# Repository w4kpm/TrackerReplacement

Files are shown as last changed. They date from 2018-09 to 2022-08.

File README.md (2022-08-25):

# Tracker replacement #

Directory Descriptions:
   * ChibiOS - A linked repo for the embedded OS
   * Firmware - Firmware code for the back panel
   * FrontPanelFirmware - Firmware code for the front panel
   * KiCad - all board design files using OSS KiCad
   * Testing - python files used for original testing of the board
   * TrackerControlCode - code use in production for updating tracker position and for resetting errors remotely. 

Included in this repo:
   * Board design files for user interface panel and tracker controller
   * Firmware for both interface panel and tracker controller
   * Examples of software used to control, reset and poll the tracker.
   * In KiCad/TrackerBackPanel and KiCad/TrackerFrontPanel are directories for gerber for board production
   * in KiCad/TrackerBackPanel/BackPanel.csv and KiCad/TrackerFrontPanel/FrontPanel.csv are parts lists
   * pos files are also there for SMT parts
   * back panel used polou VNH5019 motor driver board Item #1451 to control the motor

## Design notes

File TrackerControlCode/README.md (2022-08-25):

# Tracker control software #

A few notes about the python files included here.

A redis server was used to coordinate the line for tracker updates and
for getting data off the line for reporting. Each time we try to
communicate with the tracker, we hold a lock on the line using
redislock.

## updateTrackerPos.py ##

This python file is called every 5 minutes from a cron job, each 5
minutes it uses the lat,long azimuth of the array and the current time
to determine the optimal angle of the array based on the sun
position. At the end of the day it starts backtracking.

Before each call, it reads sensors centrally located for the entire
array for both snow and wind.

If we detect snow, we physically write out a file to the computer - if
we have a power out situation, the file is persistent and will not
return to normal operations until it is manually cleared (i.e. we are
sure that all snow is off the panels)

If wind, it tabletops the array

Each tracker controller has a (typically) 5 degree hysterisis - so
there must be a more than 5 degree change in setpoint before the
tracker will try to move again.

Each tracker has 2 angle sensors on the front and back and typically
will average the angle between these two sensors. This was to ensure
that there was no slippage or difference between the front panel angle
and the back panel angle (we had problems at one point with this
happening)

Each tracker has a max amp rating and a 'soft' amp rating, if at any
time the amps from the motor go above the high amp rating it will flag
an error and if it goes above the soft rating for a time period it
will flag an error - resetTracker.py has been used to reset these
problems.

Possible error conditions are as follows:

* #define STRAIN_ERROR 1  = Amerage above 'soft' level for a preset time period
* #define FAST_BLOW_ERROR 2 = Amperage above 'high' amp level
* #define EAST_LIMIT_ERROR 3  = east limit switch activated
* #define WEST_LIMIT_ERROR 4 = west limit switch activated
* #define STALL_ERROR 5 = too long a time of no panel movement when the motor has been engaged
* #define ANGLE_DIFF_ERROR 6 = too much difference between front and back panel
* #define EAST_ANGLE_EXCEED_ERROR 7 = Angle too high in the east direction (software defined failsafe for limit switch) 
* #define WEST_ANGLE_EXCEED_ERROR 8 = Angle too high in the west direction (software defined failsafe for limit switch) 
* #define EMERGENCY_STOP_ERROR 9 = e stop activated at console

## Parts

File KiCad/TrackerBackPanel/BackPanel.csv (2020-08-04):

Id | Designator |  | Package | Quantity | Designation | MFG | MFG Ref | Supplier | Supplier_ref | SMD | Through | Total SMD | Total Through
1 | U5 |  | Pololu VNH5019 Breakout | 0 | VNH5019 | Not Populated |  |  |  |  |  |  | 0
2 | J1 |  | RJ45 | 1 | Conn_01x08 | Amphenol | RJHSE-5080 | Mouser | 523-RJHSE-5080 |  | 1 |  | 1
3 | C11,C9,C10,C4,C2,C6 | OK | C_1206_3216Metric | 6 | .1uF | Taiyo | HMK316B7104MLHT |  | Generic .1uF 1206 10% | 1 |  | 6 | 0
4 | F1,F4,F3,F2 | ij | R_1812_4532Metric | 4 | Polyfuse_Small | littlefuse | 1812L010DR | Mouser | 576-1812L010DR | 1 |  | 4 | 0
5 | H2,H3,H1,M4 |  | MountingHole_5.3mm_M5 | 0 | MountingHole_5.3mm_M5 | Not Populated |  |  |  |  |  | 0 | 0
6 | RV3,RV2,RV4,RV1 | IJ | R_1210_3225Metric | 4 | Varistor | AVX | VC121030S620DP | Mouser | 581-VC121030S620DP | 1 |  | 4 | 0
7 | D1,D2 | OK | SOT-23 | 2 | D_TVS_x2_AAC | Bourns | CDSOT23-SM712 | Mouser | 652-CDSOT23-SM712 | 1 |  | 2 | 0
8 | J9,J8 |  | TerminalBlock_Altech_AK300-4_P5.00mm | 2 | Conn_01x04 | Phoenix Contact | 1890989 | Mouser | 651-1890989 |  | 1 | 0 | 2
9 | J7,J6,J5,J4,J11 |  | TerminalBlock_Altech_AK300-2_P5.00mm | 5 | Conn_01x02 | Phoenix Contact | 1711026 | Mouser | 651-1711026 |  | 1 | 0 | 5
10 | C7,C3,C1,C5,C14,C15 | OK | C_1206_3216Metric | 6 | 1uF | vishay | VJ1206Y105KXQTW1BC |  | Generic 1uF 1206 10% | 1 |  | 6 | 0
11 | U4,U3 | OK | SOIC-8_3.9x4.9mm_P1.27mm | 2 | SN65HV7X | Texas Insturments | SN65HVD72D | mouser | 595-SN65HVD72D | 1 |  | 2 | 0
12 | U2 |  | TO-220-3_Vertical | 1 | R-78B3.3-2.0 | RECOM power | R-78E3.3-0.5 | Mouser | 919-R-78E3.3-0.5 |  | 1 | 0 | 1
13 | J2 |  | PinHeader_2x04_P2.54mm_Vertical | 0 | Conn_02x04_Odd_Even | Not Populated!! |  |  |  |  |  | 0 | 0
14 | J3 |  | PinHeader_1x06_P2.54mm_Vertical | 0 | Conn_01x06 | Not Populated!! |  |  |  |  |  | 0 | 0
15 | U1 | OK | LQFP-100_14x14mm_P0.5mm | 1 | STM32F303V(B-C)Tx_u | STM | STM32F303VCT6 | mouser | 511-STM32F303VCT6 | 1 |  | 1 | 0
16 | J10 |  | TerminalBlock_Altech_AK300-3_P5.00mm | 1 | Conn_01x03 | Phoenix Contact | 1890976 | Mouser | 651-1890976 |  | 1 | 0 | 1
17 | C12,C8 | IJ | CP_Elec_10x10 | 2 | 220uF | Cornell Dubilier - CDE | 227AXZ050M |  | 598-227AXZ050M | 1 |  | 2 | 0
18 | C13,C16 | OK | CP_Elec_6.3x5.2 | 2 | 100uF | Cornell Dubilier | 107SML035M | Mouser | 598-107SML035M | 1 |  | 2 | 0
19 | SW1 |  | SW_DIP_SPSTx08_Slide_6.7x21.88mm_W8.61mm_P2.54mm_LowProfile | 1 | SW-DIP-8 | CTS Electronic Components | 219-8MST | Mouser | 774-2198MST | 1 |  | 1 | 0
20 | R1,R2,R3,R4 |  | TBU | 4 | TBU | Bourns | TBU-CA065-200-WH | Mouser | 652-TBU-CA065-200-WH | 1 |  | 4 | 0
 |  |  |  | 44 |  |  |  |  |  | 11 | 5 | 34 | 10

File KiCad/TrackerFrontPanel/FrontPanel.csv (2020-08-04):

Id | Designator | Package | Quantity | Designation | MFG | MFG Ref | Supplier | Supplier Ref | SMD | Through | Total SMD | Total Through
1 | C1 | CP_Elec_5x5.3 | 1 | 100uF | Cornell Dubilier | 107SML035M | Mouser | 598-107SML035M | 1 |  | 1
2 | C2,C4,C6,C8 | C_1206 | 4 | 1uF | vishay | VJ1206Y105KXQTW1BC |  | Generic 1uF 1206 10% | 1 |  | 4
3 | C3,C5,C7,C9 | C_1206 | 4 | .1uF | Taiyo | HMK316B7104MLHT |  | Generic .1uF 1206 10% | 1 |  | 4
4 | D1,D2,D3,D4 | D_1206 | 4 | LED | Wurth | 156120VS75300 | mouser | 710-156120VS75300 | 1 |  | 4
5 | J2 | Pin_Header_Straight_1x20_Pitch2.54mm | 0 | Conn_01x20 | Not Populated |  |  |  |  |  | 0
6 | R1,R2,R3,R4 | R_1206 | 4 | 330 | KOA Speer - Generic OK | RK73B2BTTE331J | Mouser | 660-RK73B2BTTE331J | 1 |  | 4
7 | SW1,SW2,SW3,SW4,SW5,SW6,SW7,SW8,SW9,SW10 | PTS125 | 10 | TS001 | C&K | PTS125SK12SMTR2LFS | Mouser | 611-PTS125SK12SMTR2 | 1 |  | 10
8 | U1 | LQFP-100_14x14mm_Pitch0.5mm | 1 | STM32F303V(B-C)Tx_u | STM | STM32F303VCT6 | mouser | 511-STM32F303VCT6 | 1 |  | 1
9 | J1 | RJ45 | 1 | Conn_01x08 | Amphenol | RJHSE-5080 | Mouser | 523-RJHSE-5080 |  | 1 |  | 1
10 | J4 | Pin_Header_Straight_1x06_Pitch2.54mm | 0 | Conn_01x06 | Not Populated
11 | h2,h1,h4,h5,h6,h3 | MountingHole_3.5mm | 0 | MountingHole_3.5mm | Not Populated
12 | h9,h10,h7,h8 | MountingHole_2.5mm | 0 | MountingHole_2.5mm | Not Populated
13 | J3 | Pin_Header_Straight_2x04_Pitch2.54mm | 0 | Conn_02x04_Odd_Even | Not Populated
 |  |  | 29 |  |  |  |  |  | 7 | 1 | 28 | 1

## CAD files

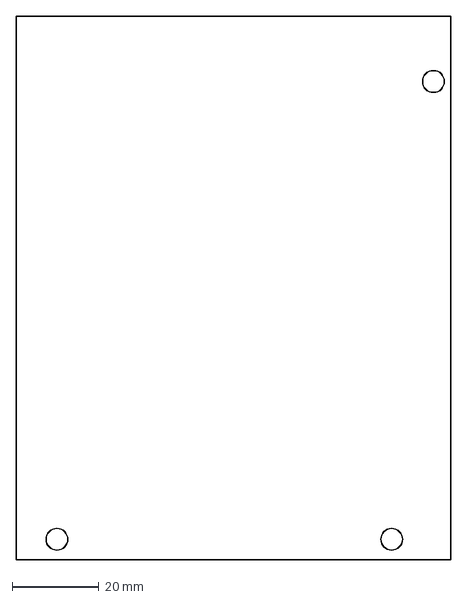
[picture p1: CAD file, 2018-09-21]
BackPanel.dxf
100.0 x 125.0 mm

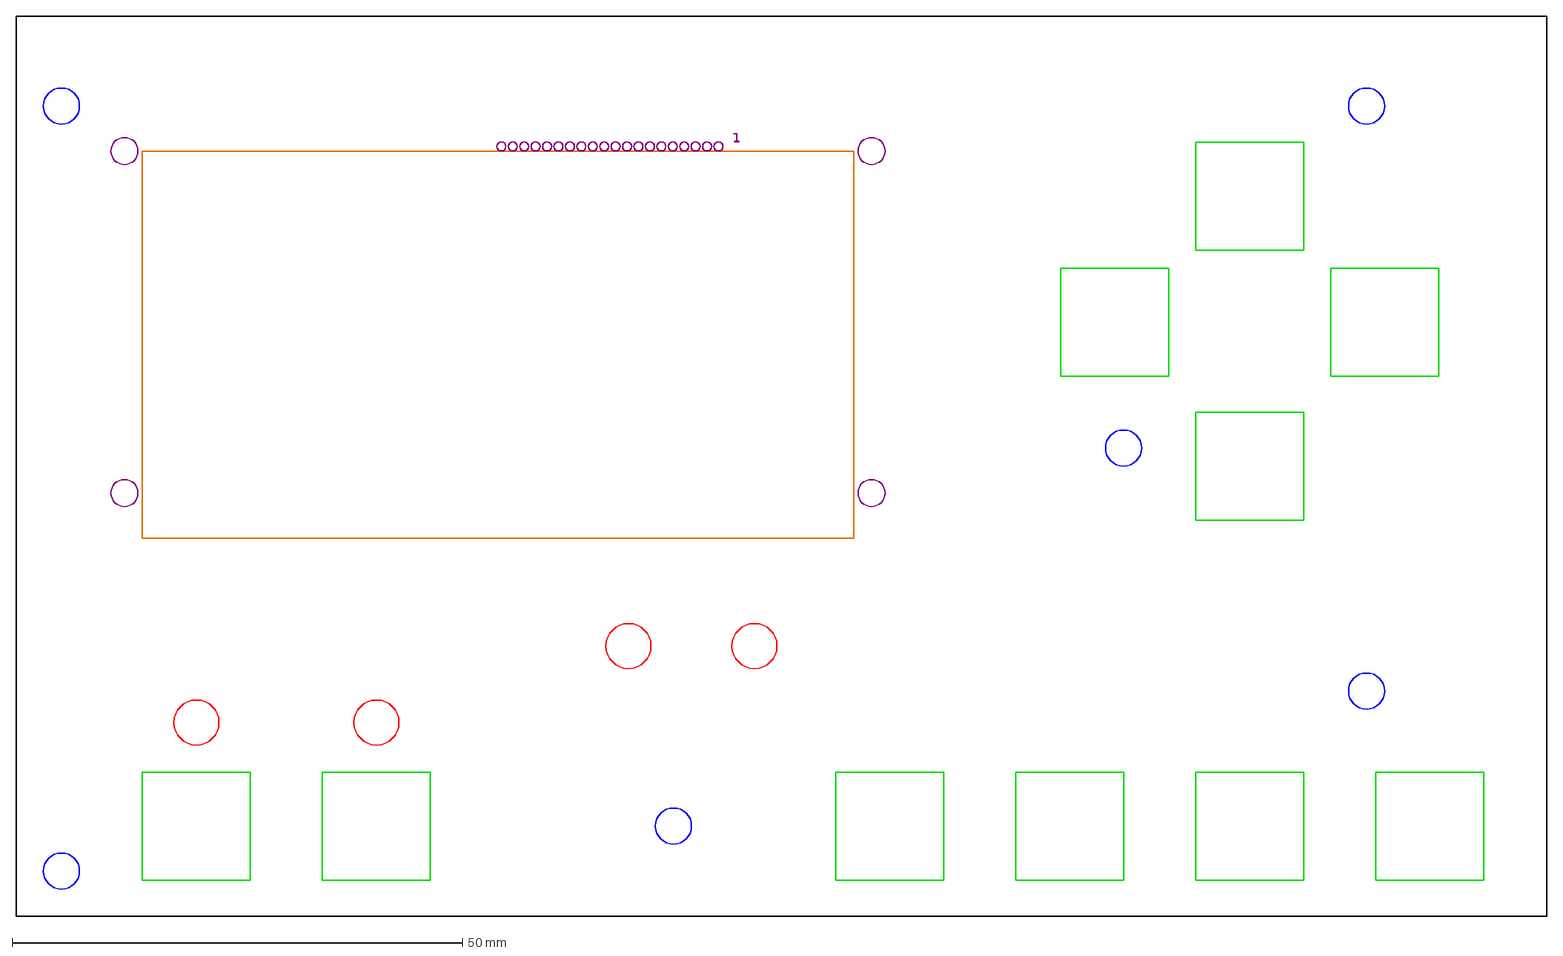
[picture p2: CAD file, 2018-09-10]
FrontPanel.dxf
1

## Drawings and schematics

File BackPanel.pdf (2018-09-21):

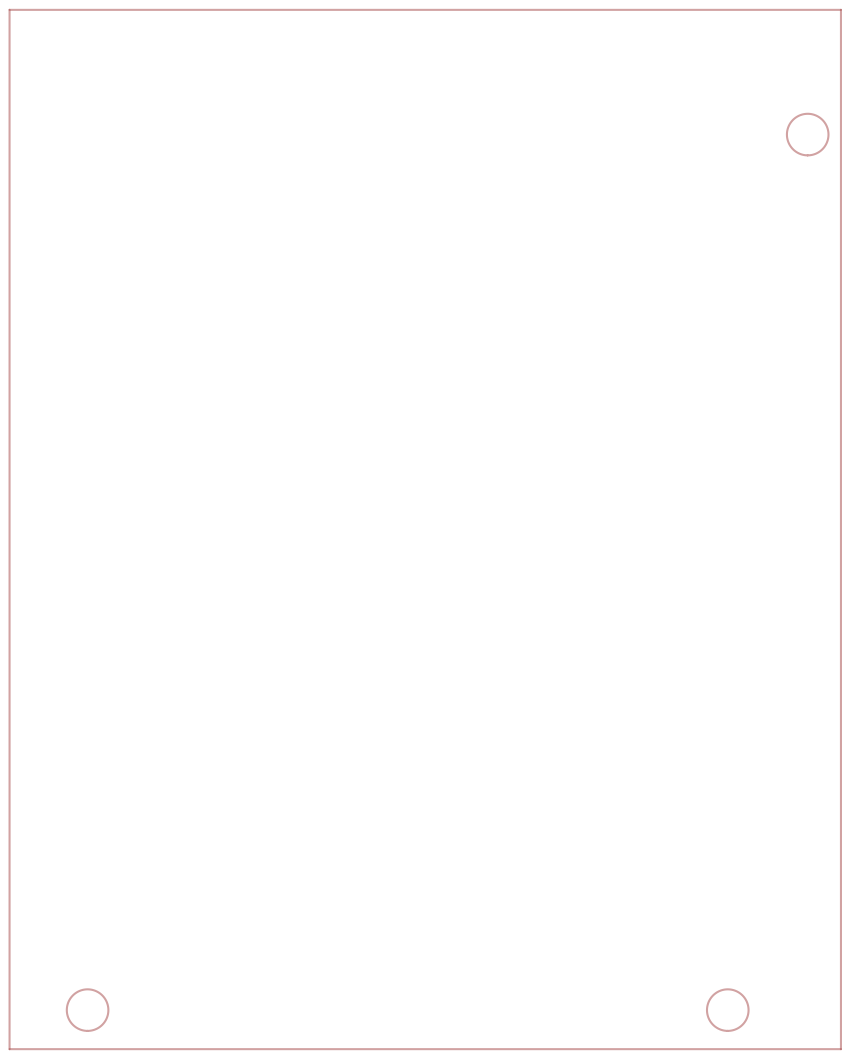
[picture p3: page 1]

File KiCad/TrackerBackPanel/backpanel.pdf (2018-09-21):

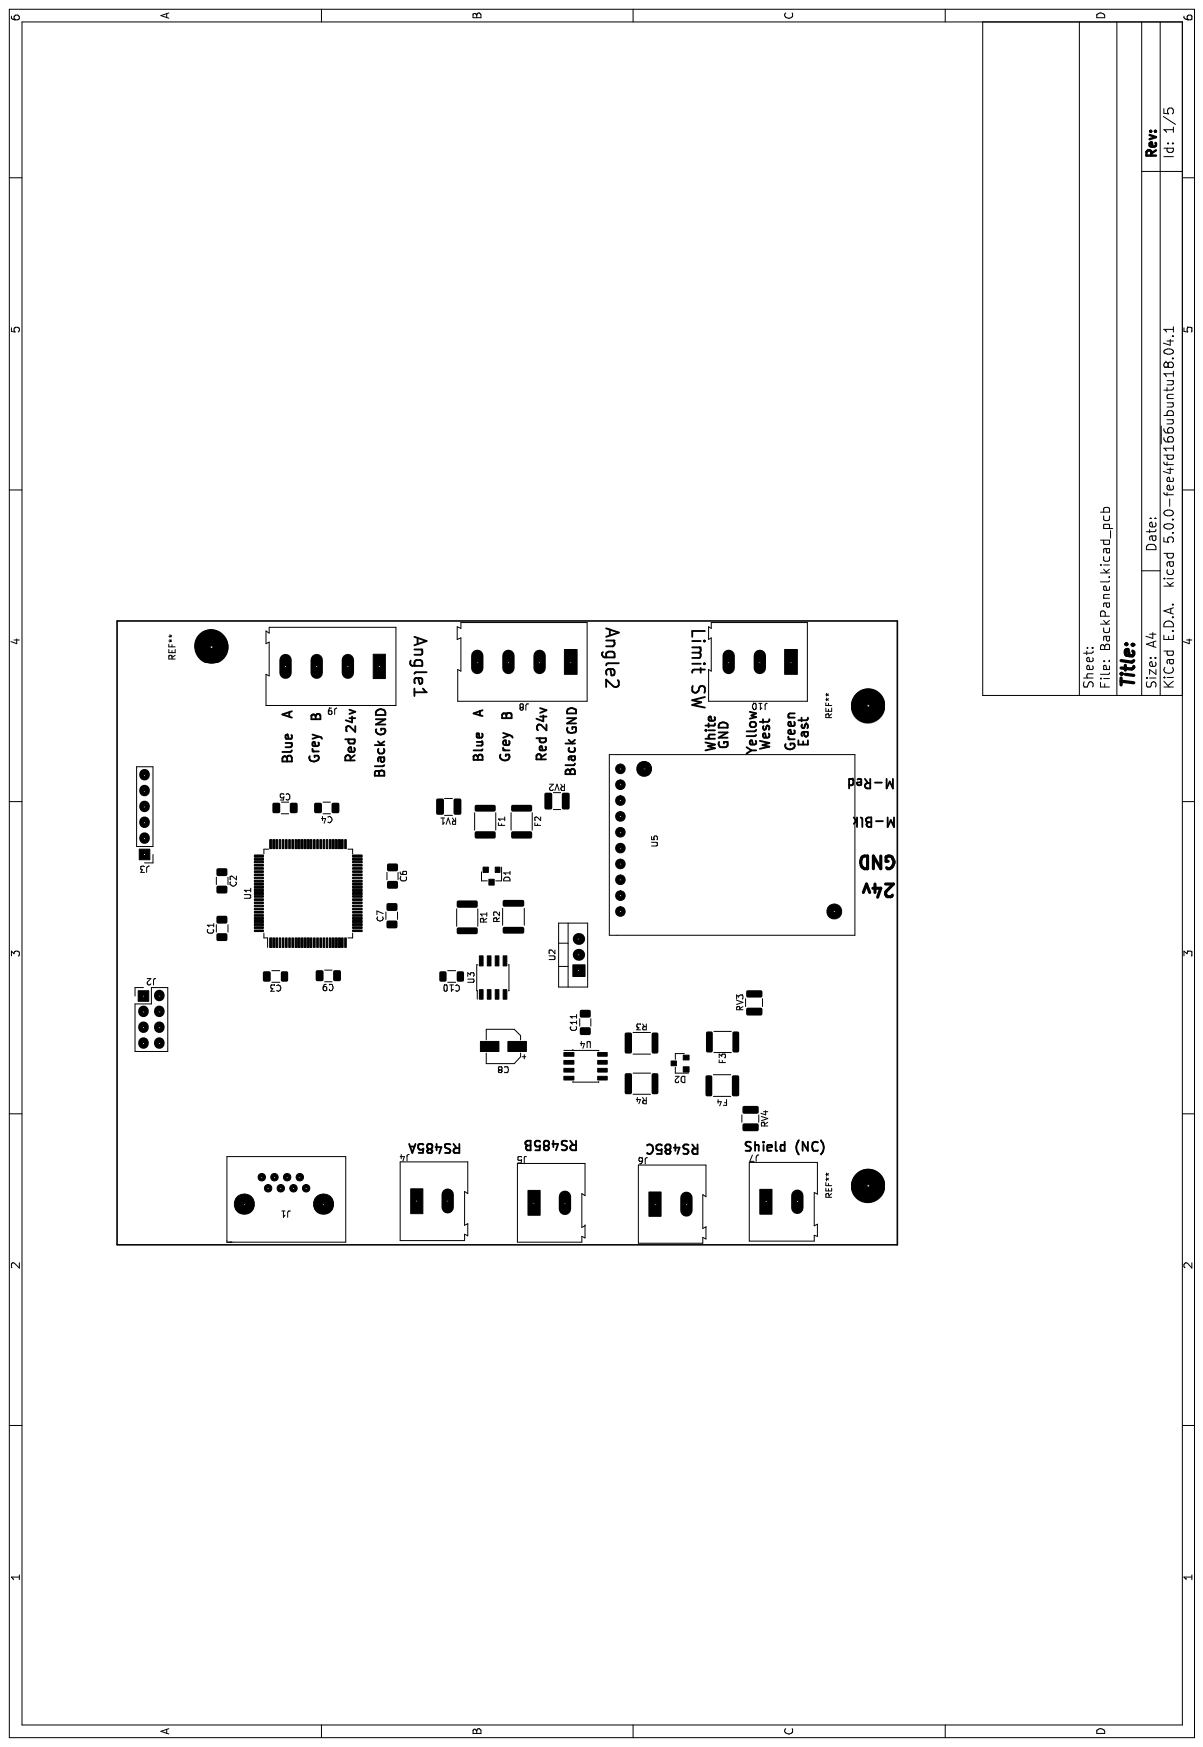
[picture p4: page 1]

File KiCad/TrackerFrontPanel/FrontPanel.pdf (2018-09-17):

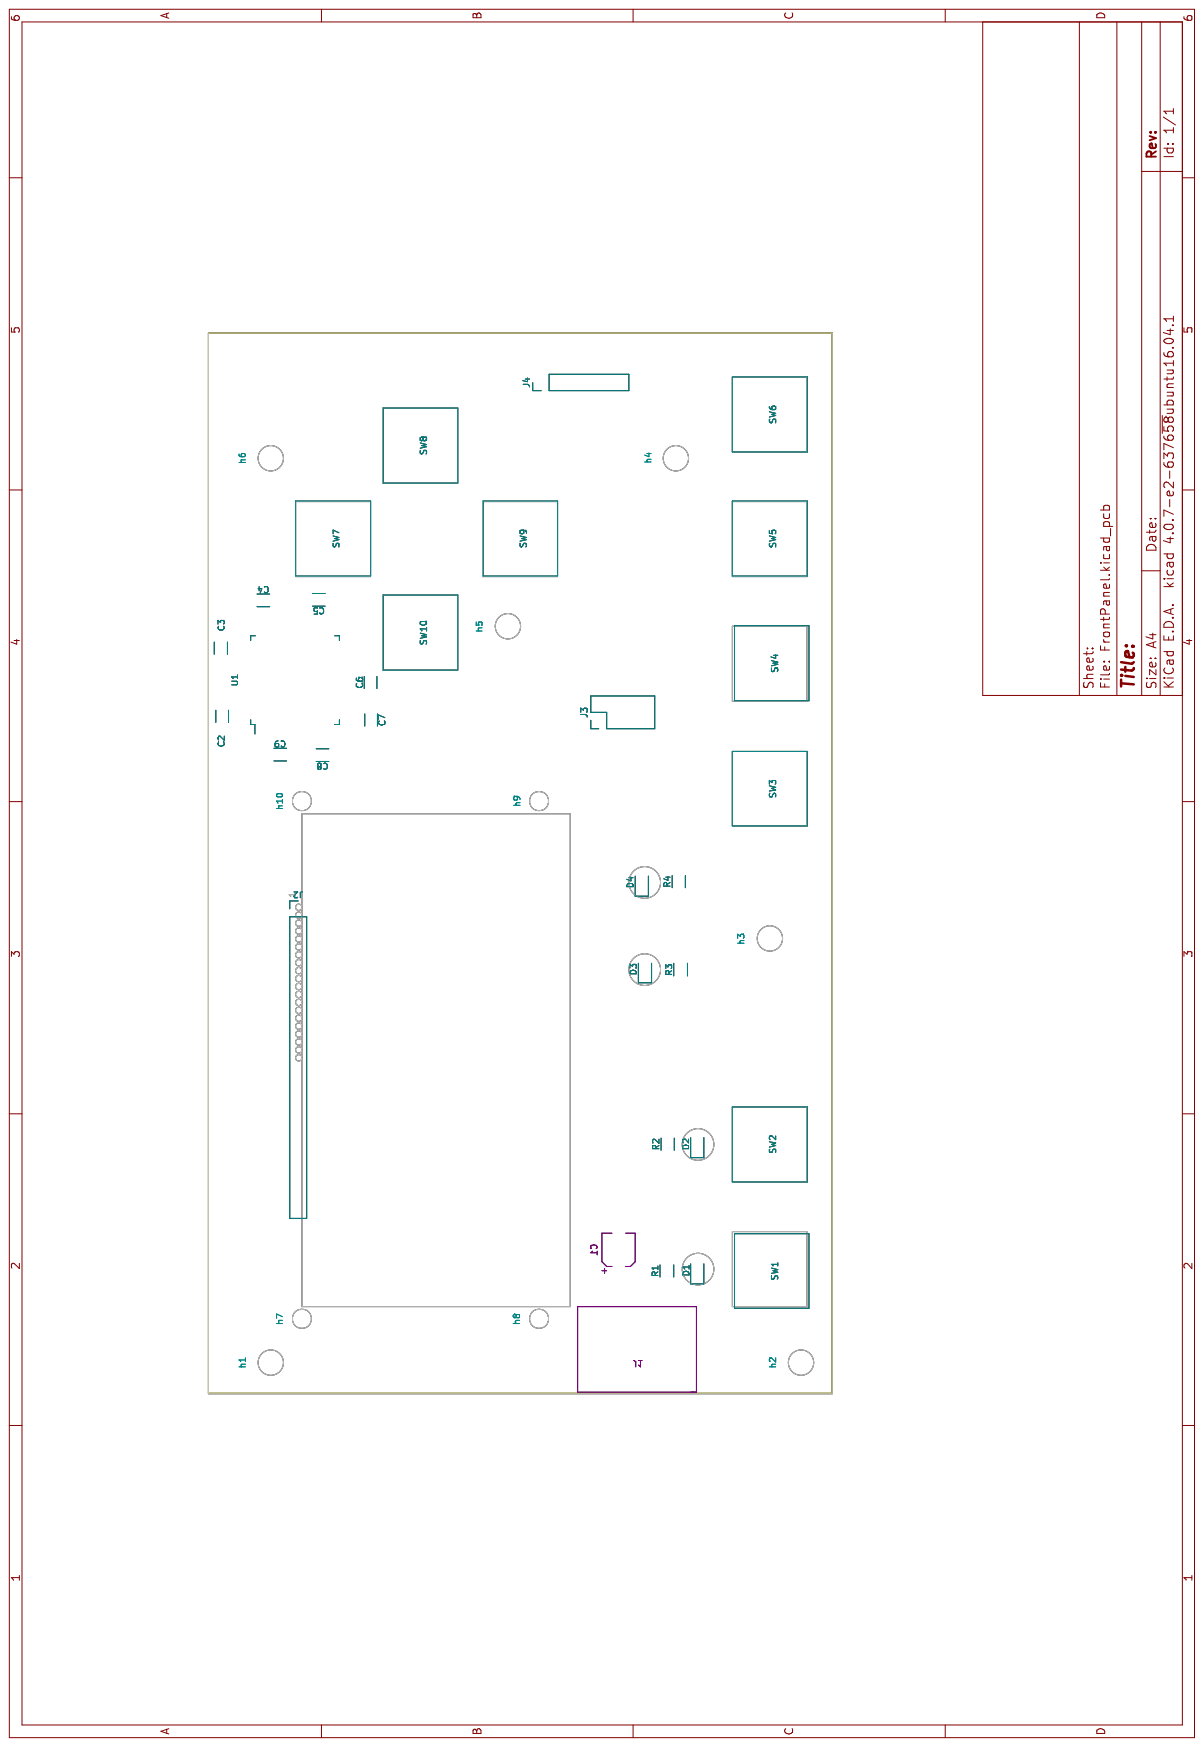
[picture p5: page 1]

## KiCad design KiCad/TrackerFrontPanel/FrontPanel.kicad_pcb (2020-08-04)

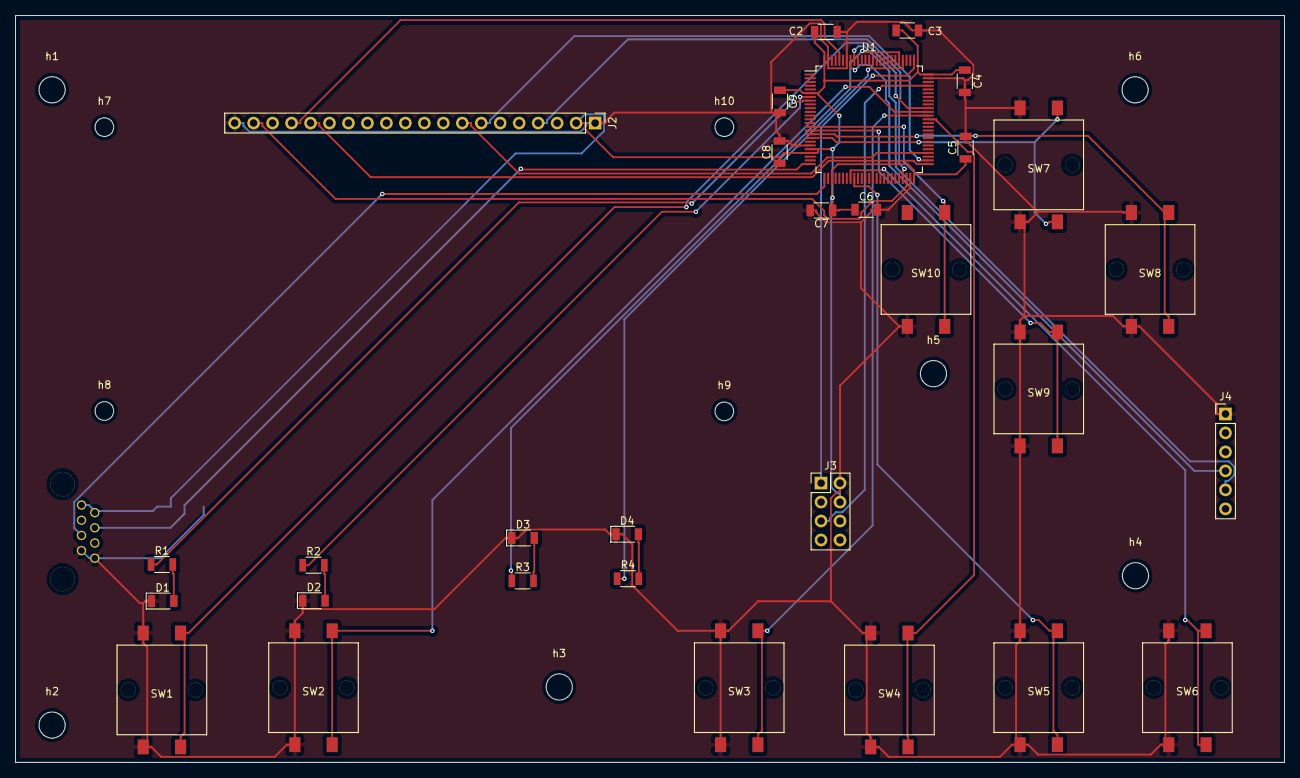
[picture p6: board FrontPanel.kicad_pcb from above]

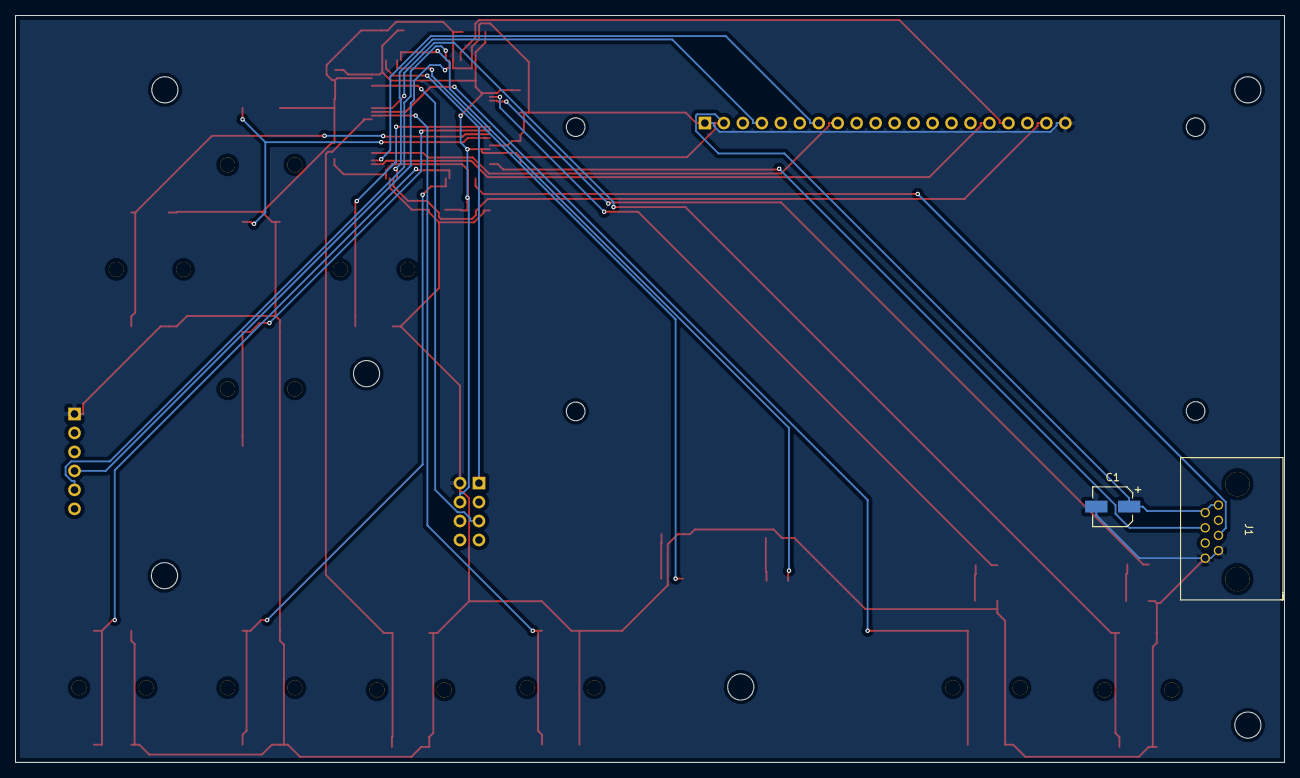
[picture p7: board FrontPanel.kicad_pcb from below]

Board: 2 copper layers, 169.9 x 100.0 mm, 42 parts (2 on the bottom side), 32 nets.

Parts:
C1: 100uF; CP_Elec_5x5.3
C2, C4, C6, C8: 1uF; C_1206
C3, C5, C7, C9: .1uF; C_1206
D1, D2, D3, D4: LED; D_1206
J1: Conn_01x08; RJ45
J2: Conn_01x20; Pin_Header_Straight_1x20_Pitch2.54mm
J3: Conn_02x04_Odd_Even; Pin_Header_Straight_2x04_Pitch2.54mm
J4: Conn_01x06; Pin_Header_Straight_1x06_Pitch2.54mm
R1, R2, R3, R4: R; R_1206
SW1, SW2, SW3, SW4, SW5, SW6, SW7, SW8, SW9, SW10: TS001; PTS125
U1: STM32F303V(B-C)Tx_u; LQFP-100_14x14mm_Pitch0.5mm
h1, h2, h3, h4, h5, h6: MountingHole_3.5mm
h7, h8, h9, h10: MountingHole_2.5mm

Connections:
+3V3: C1.1, C2.1, C3.1, C4.1, C5.1, C6.1, C7.1, C8.1, C9.1, J1.1, J1.2, J2.2, J3.4, U1.6, U1.21, U1.22, U1.28, U1.50, U1.75, U1.100
/RX: J1.5, U1.26
/TX: J1.4, U1.25
GND: C1.2, C2.2, C3.2, C4.2, C5.2, C6.2, C7.2, C8.2, C9.2, D1.1, D2.1, D3.1, D4.1, J1.7, J1.8, J2.1, J2.20, J3.2, J4.1, SW1.3, SW1.4, SW2.3, SW2.4, SW3.3, SW3.4, SW4.3, SW4.4, SW5.3, SW5.4, SW6.3, SW6.4, SW7.3, SW7.4, SW8.3, SW8.4, SW9.3, SW9.4, SW10.4, U1.20, U1.49, U1.74, U1.94, U1.99
unnamed: D1.2, R1.2
unnamed: D2.2, R2.2
unnamed: D3.2, R3.2
unnamed: D4.2, R4.2
unnamed: J2.4, U1.47
unnamed: J2.7, U1.52
unnamed: J2.8, U1.54
unnamed: J2.16, U1.51
unnamed: J2.17, U1.96
unnamed: J2.19, U1.48
unnamed: J3.1, U1.76
unnamed: J3.5, U1.72
unnamed: J4.4, U1.93
unnamed: J4.5, U1.92
unnamed: R1.1, U1.8
unnamed: R2.1, U1.7
unnamed: R3.1, U1.80
unnamed: R4.1, U1.79
unnamed: SW1.1, SW1.2, U1.66
unnamed: SW2.1, SW2.2, U1.65
unnamed: SW3.1, SW3.2, U1.64
unnamed: SW4.1, SW4.2, U1.63
unnamed: SW5.1, SW5.2, U1.34
unnamed: SW6.1, SW6.2, U1.33
unnamed: SW7.1, SW7.2, U1.18
unnamed: SW8.1, SW8.2, U1.17
unnamed: SW9.1, SW9.2, U1.16
unnamed: SW10.1, SW10.2, U1.15

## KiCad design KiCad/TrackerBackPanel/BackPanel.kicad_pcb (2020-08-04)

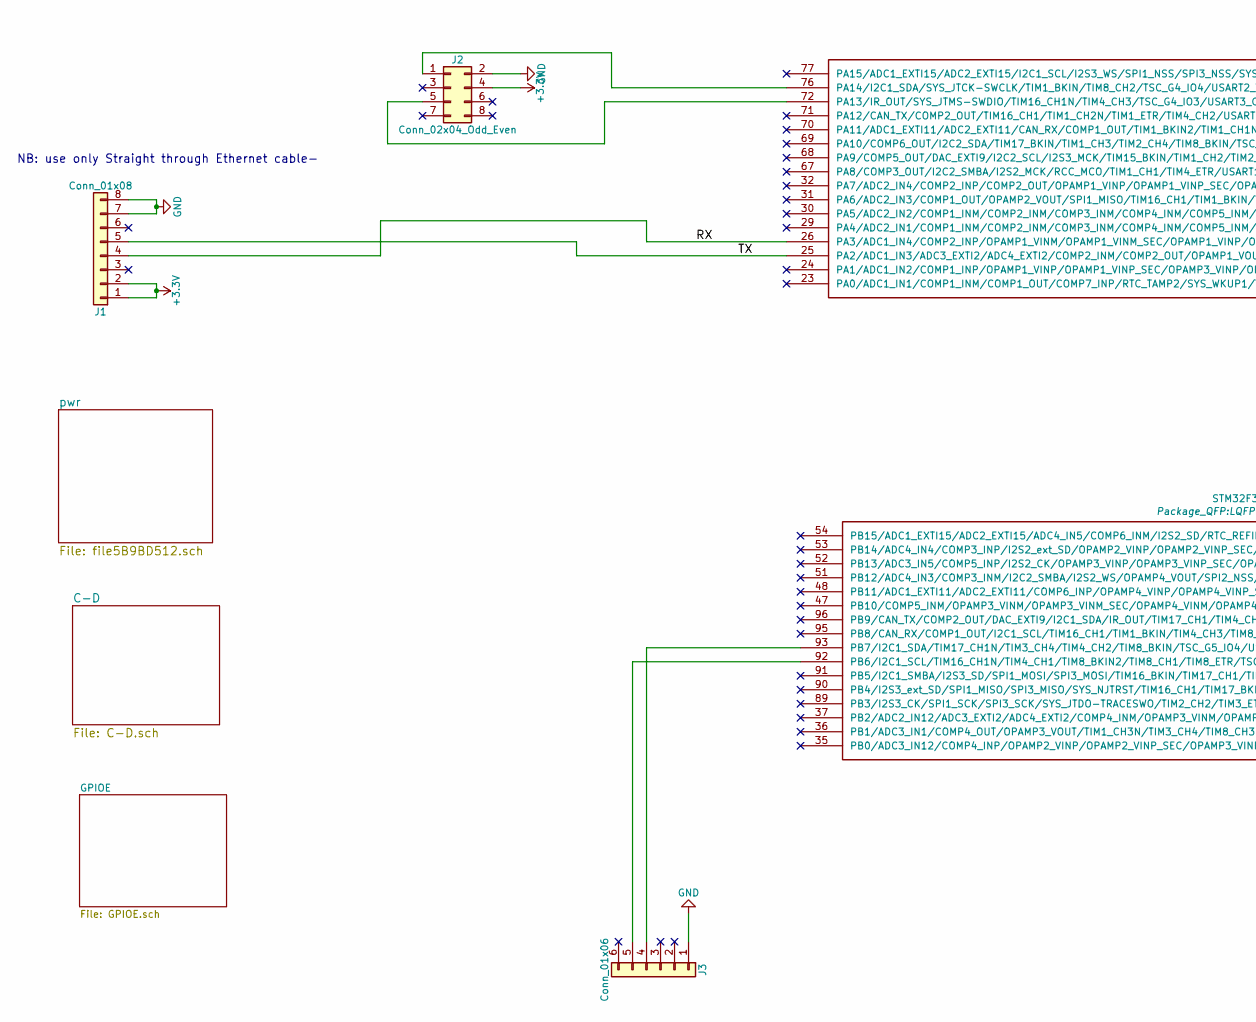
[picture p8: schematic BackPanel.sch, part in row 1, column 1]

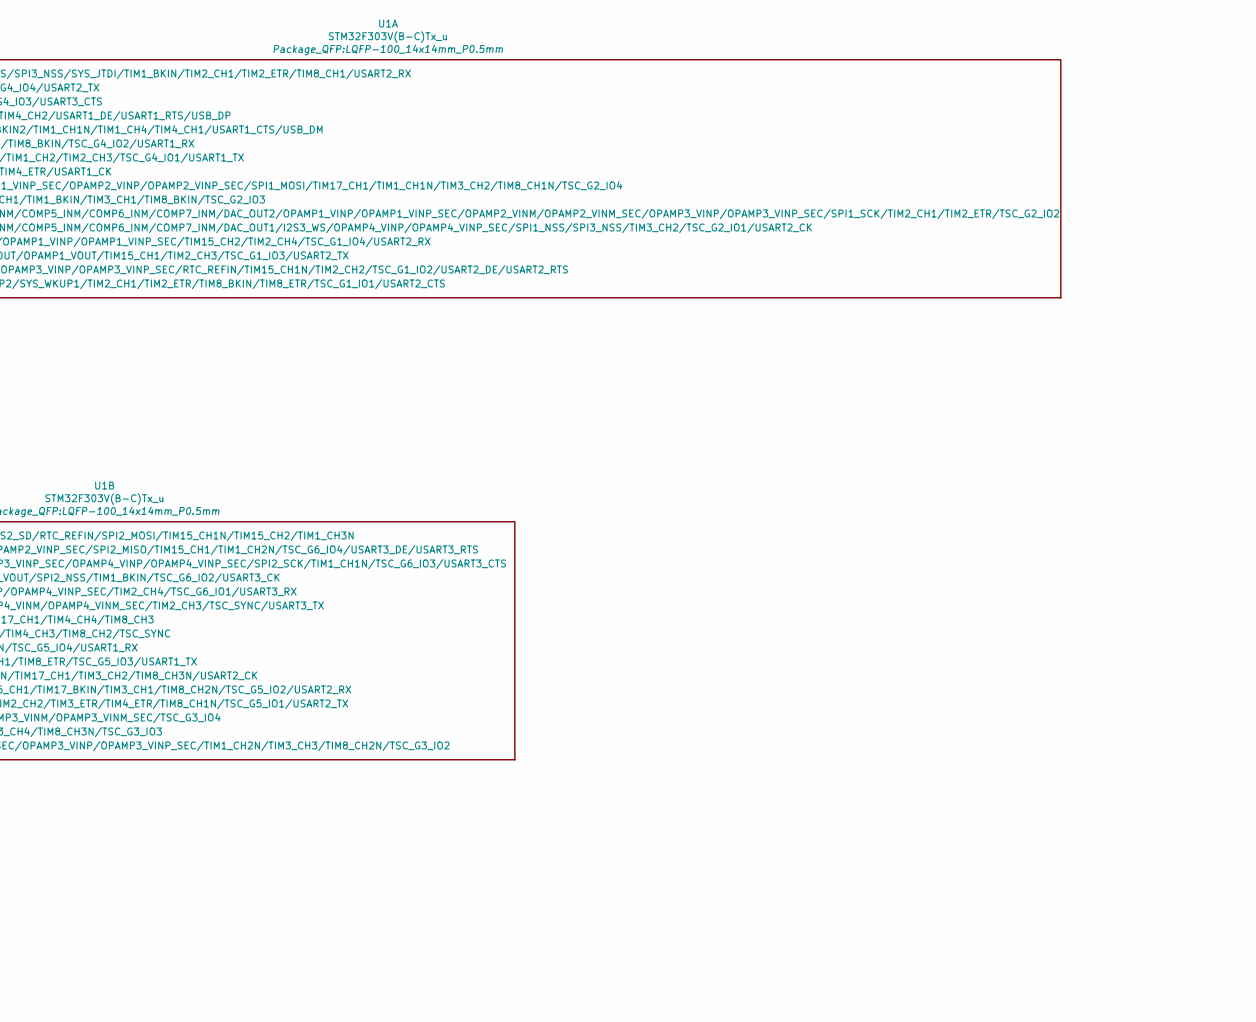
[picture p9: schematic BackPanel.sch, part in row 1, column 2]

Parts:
J1: Conn_01x08; RJ45
J2: Conn_02x04_Odd_Even; PinHeader_2x04_P2.54mm_Vertical
J3: Conn_01x06; PinHeader_1x06_P2.54mm_Vertical
U1: STM32F303V(B-C)Tx_u; LQFP-100_14x14mm_P0.5mm

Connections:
+3V3: J1.1, J1.2, J2.4; also elsewhere on the board
/RX: J1.4, U1.26 (PA3/ADC1_IN4/COMP2_INP/OPAMP1_VINM/OPAM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)
/TX: J1.5, U1.25 (PA2/ADC1_IN3/ADC3_EXTI2/ADC4_EXTI2/COMP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)
GND: J1.7, J1.8, J2.2, J3.1; also elsewhere on the board
unnamed: J2.1, U1.76 (PA14/I2C1_SDA/SYS_JTCK-SWCLK/TIM1_BKIN/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)
unnamed: J2.5, U1.72 (PA13/IR_OUT/SYS_JTMS-SWDIO/TIM16_CH1N/T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)
unnamed: J3.4, U1.93 (PB7/I2C1_SDA/TIM17_CH1N/TIM3_CH4/TIM4_C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)
unnamed: J3.5, U1.92 (PB6/I2C1_SCL/TIM16_CH1N/TIM4_CH1/TIM8_B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)

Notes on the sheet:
NB: use only Straight through Ethernet cable-

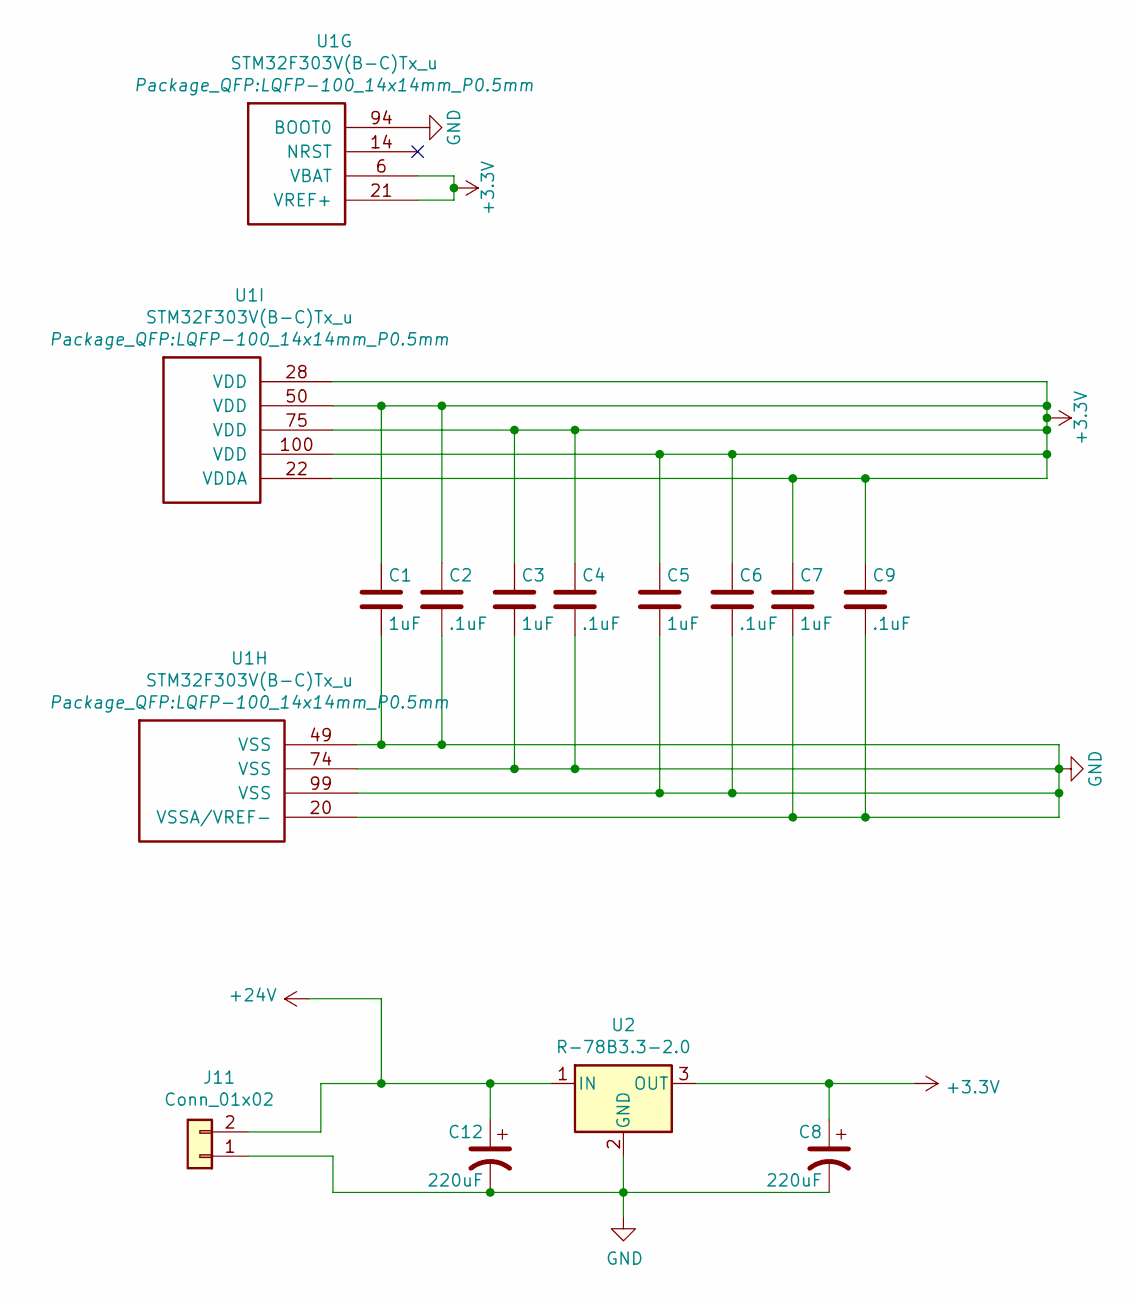
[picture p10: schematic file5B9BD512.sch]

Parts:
C1, C3, C5, C7: 1uF; C_1206_3216Metric
C2, C4, C6, C9: .1uF; C_1206_3216Metric
C8, C12: 220uF; CP_Elec_10x10
J11: Conn_01x02; TerminalBlock_Altech_AK300-2_P5.00mm
U1: STM32F303V(B-C)Tx_u; LQFP-100_14x14mm_P0.5mm
U2: R-78B3.3-2.0; TO-220-3_Vertical

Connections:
+3V3: C1.1, C2.1, C3.1, C4.1, C5.1, C6.1, C7.1, C8.1, C9.1, U1.6 (VBAT), U1.21 (VREF+), U1.22 (VDDA), U1.28 (VDD), U1.50 (VDD), U1.75 (VDD), U1.100 (VDD), U2.3 (OUT); also elsewhere on the board
+24V: C12.1, J11.2, U2.1 (IN); also elsewhere on the board
GND: C1.2, C2.2, C3.2, C4.2, C5.2, C6.2, C7.2, C8.2, C9.2, C12.2, J11.1, U1.20 (VSSA/VREF-), U1.49 (VSS), U1.74 (VSS), U1.94 (BOOT0), U1.99 (VSS), U2.2 (GND); also elsewhere on the board

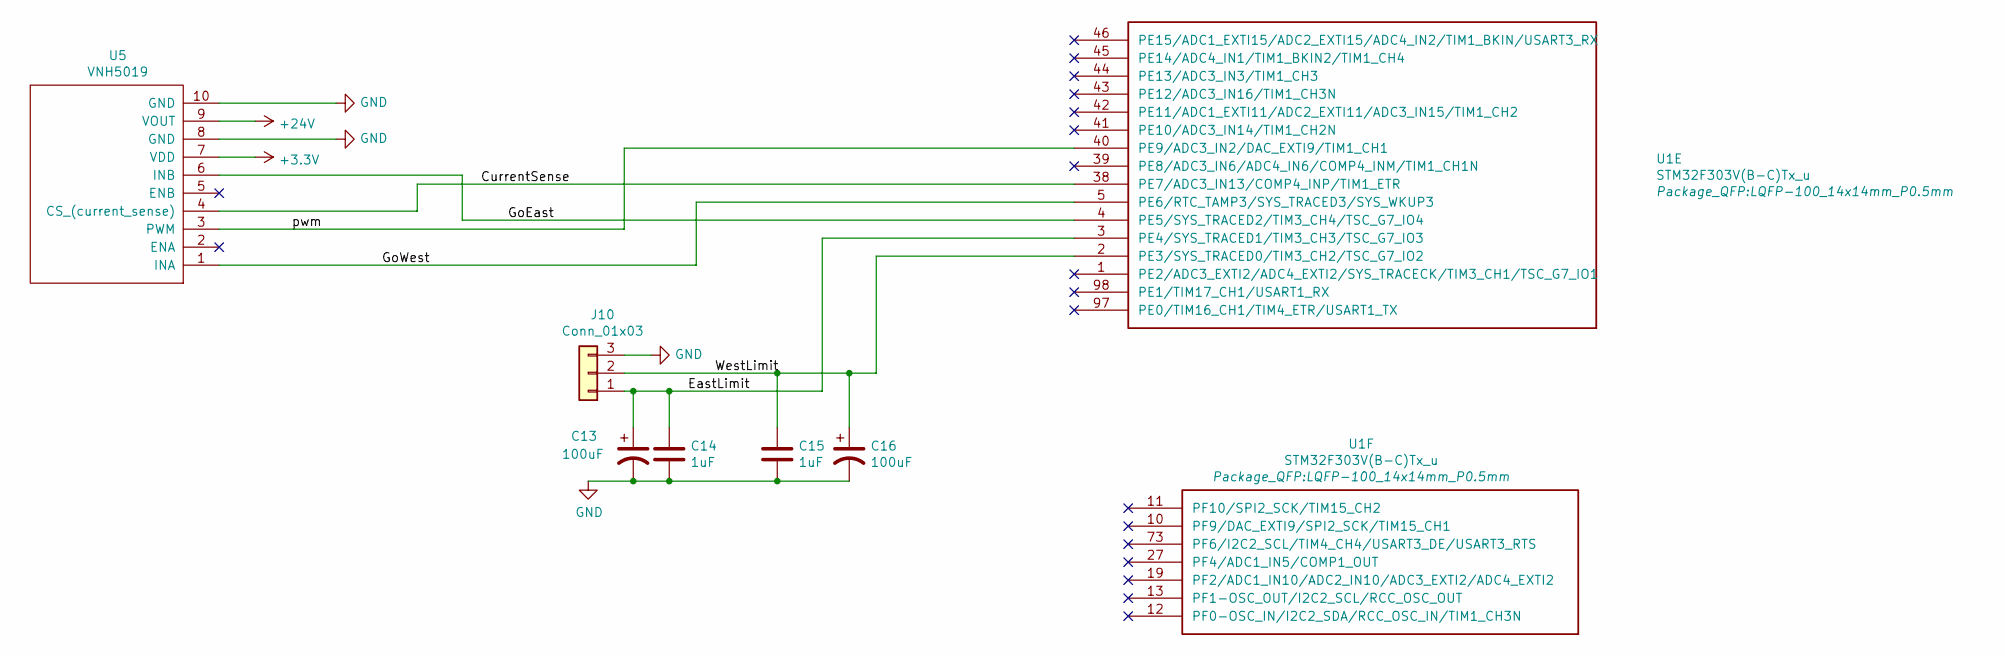
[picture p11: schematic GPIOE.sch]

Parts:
C13, C16: 100uF; CP_Elec_6.3x5.2
C14, C15: 1uF; C_1206_3216Metric
J10: Conn_01x03; TerminalBlock_Altech_AK300-3_P5.00mm
U1: STM32F303V(B-C)Tx_u; LQFP-100_14x14mm_P0.5mm
U5: VNH5019; Pololu VNH5019 Breakout

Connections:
+3V3: U5.7 (VDD); also elsewhere on the board
+24V: U5.9 (VOUT); also elsewhere on the board
/GPIOE/CurrentSense: U1.38 (PE7/ADC3_IN13/COMP4_INP/TIM1_ETR), U5.4 (CS_(current_sense))
/GPIOE/pwm: U1.40 (PE9/ADC3_IN2/DAC_EXTI9/TIM1_CH1), U5.3 (PWM)
GND: C13.2, C14.2, C15.2, C16.2, J10.3, U5.8 (GND), U5.10 (GND); also elsewhere on the board

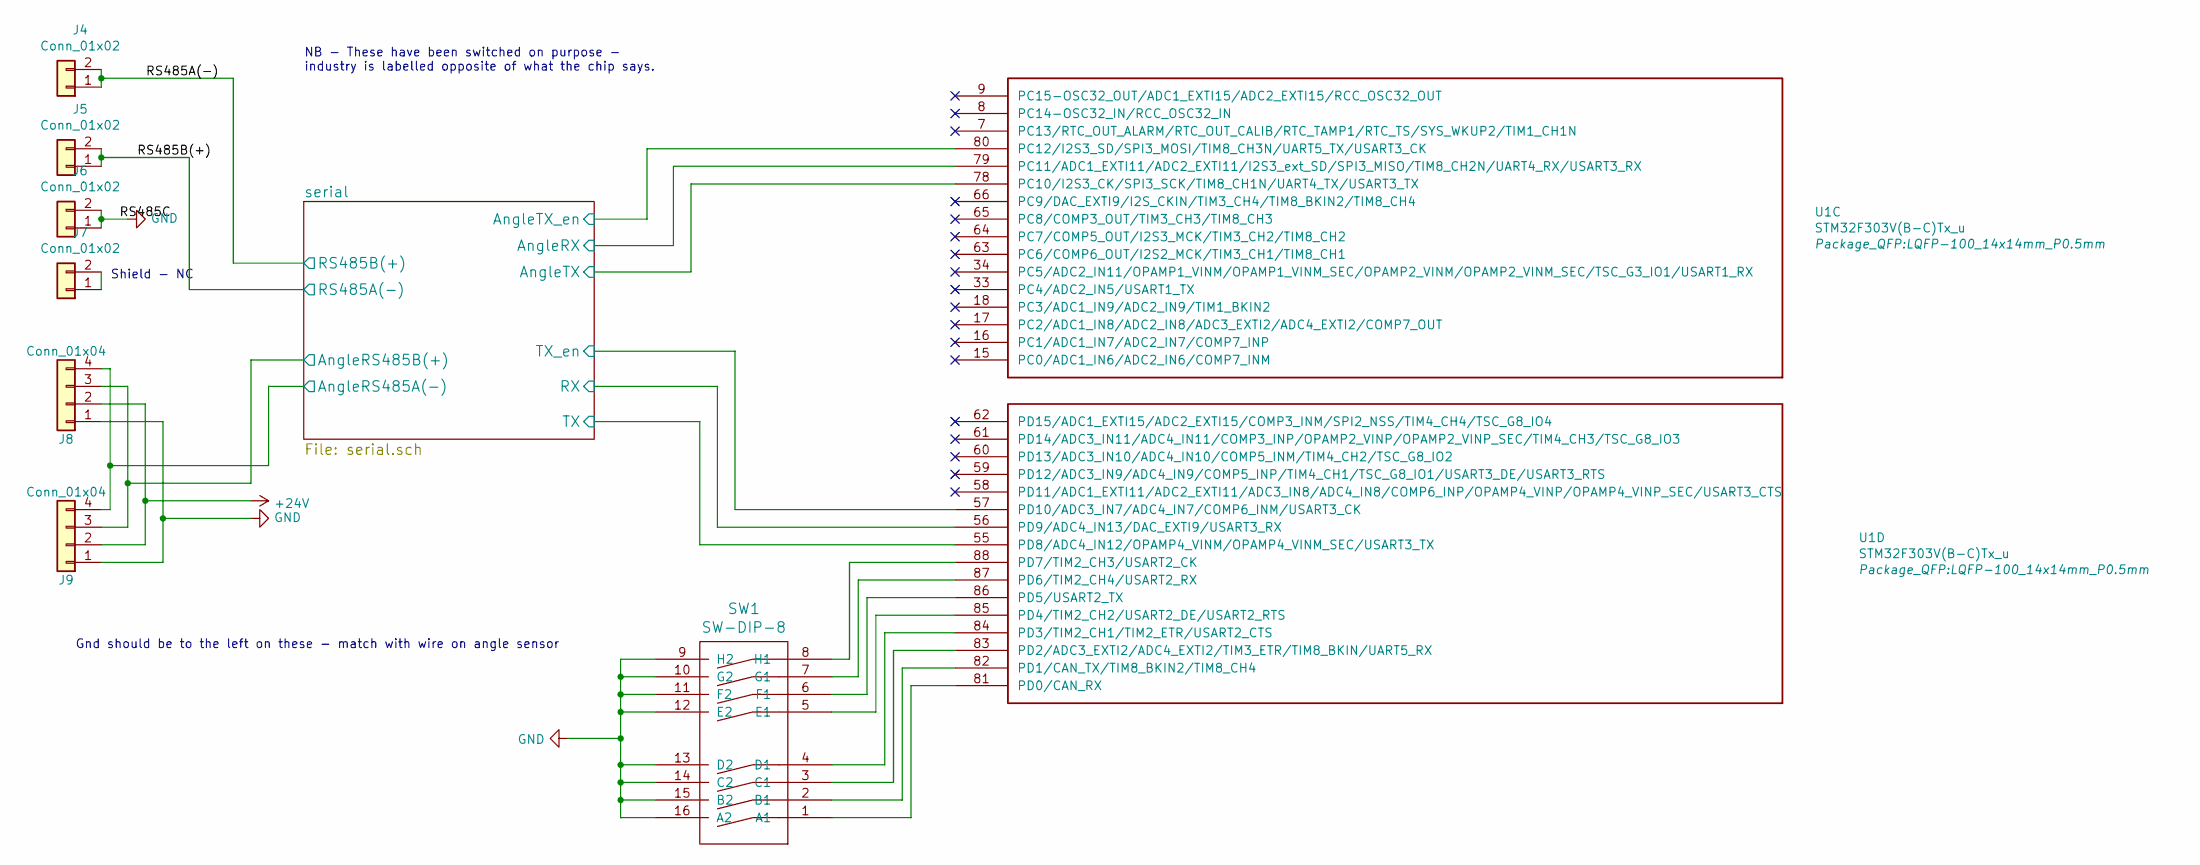
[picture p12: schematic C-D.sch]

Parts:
J4, J5, J6, J7: Conn_01x02; TerminalBlock_Altech_AK300-2_P5.00mm
J8, J9: Conn_01x04; TerminalBlock_Altech_AK300-4_P5.00mm
SW1: SW-DIP-8; SW_DIP_SPSTx08_Slide_6.7x21.88mm_W8.61mm_P2.54mm_LowProfile
U1: STM32F303V(B-C)Tx_u; LQFP-100_14x14mm_P0.5mm

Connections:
+24V: J8.2, J9.2; also elsewhere on the board
/C-D/RS485A(-): J4.1, J4.2; also elsewhere on the board
/C-D/RS485B(+): J5.1, J5.2; also elsewhere on the board
/C-D/serial/AngleRS485A(-): J8.4, J9.4; also elsewhere on the board
/C-D/serial/AngleRS485B(+): J8.3, J9.3; also elsewhere on the board
/C-D/serial/AngleRX: U1.79 (PC11/ADC1_EXTI11/ADC2_EXTI11/I2S3_ext_S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); also elsewhere on the board
/C-D/serial/AngleTX: U1.78 (PC10/I2S3_CK/SPI3_SCK/TIM8_CH1N/UART4_T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); also elsewhere on the board
/C-D/serial/AngleTX_en: U1.80 (PC12/I2S3_SD/SPI3_MOSI/TIM8_CH3N/UART5_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); also elsewhere on the board
/C-D/serial/RX: U1.56 (PD9/ADC4_IN13/DAC_EXTI9/USART3_RX); also elsewhere on the board
/C-D/serial/TX: U1.55 (PD8/ADC4_IN12/OPAMP4_VINM/OPAMP4_VINM_S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); also elsewhere on the board
/C-D/serial/TX_en: U1.57 (PD10/ADC3_IN7/ADC4_IN7/COMP6_INM/USART3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); also elsewhere on the board
GND: J6.1, J6.2, J8.1, J9.1, SW1.9 (H2), SW1.10 (G2), SW1.11 (F2), SW1.12 (E2), SW1.13 (D2), SW1.14 (C2), SW1.15 (B2), SW1.16 (A2); also elsewhere on the board
unnamed: J7.1, J7.2
unnamed: SW1.1 (A1), U1.81 (PD0/CAN_RX)
unnamed: SW1.2 (B1), U1.82 (PD1/CAN_TX/TIM8_BKIN2/TIM8_CH4)
unnamed: SW1.3 (C1), U1.83 (PD2/ADC3_EXTI2/ADC4_EXTI2/TIM3_ETR/TIM8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)
unnamed: SW1.4 (D1), U1.84 (PD3/TIM2_CH1/TIM2_ETR/USART2_CTS)
unnamed: SW1.5 (E1), U1.85 (PD4/TIM2_CH2/USART2_DE/USART2_RTS)
unnamed: SW1.6 (F1), U1.86 (PD5/USART2_TX)
unnamed: SW1.7 (G1), U1.87 (PD6/TIM2_CH4/USART2_RX)
unnamed: SW1.8 (H1), U1.88 (PD7/TIM2_CH3/USART2_CK)

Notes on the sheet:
Shield - NC
Gnd should be to the left on these - match with wire on angle sensor
NB - These have been switched on purpose - industry is labelled opposite of what the chip says.

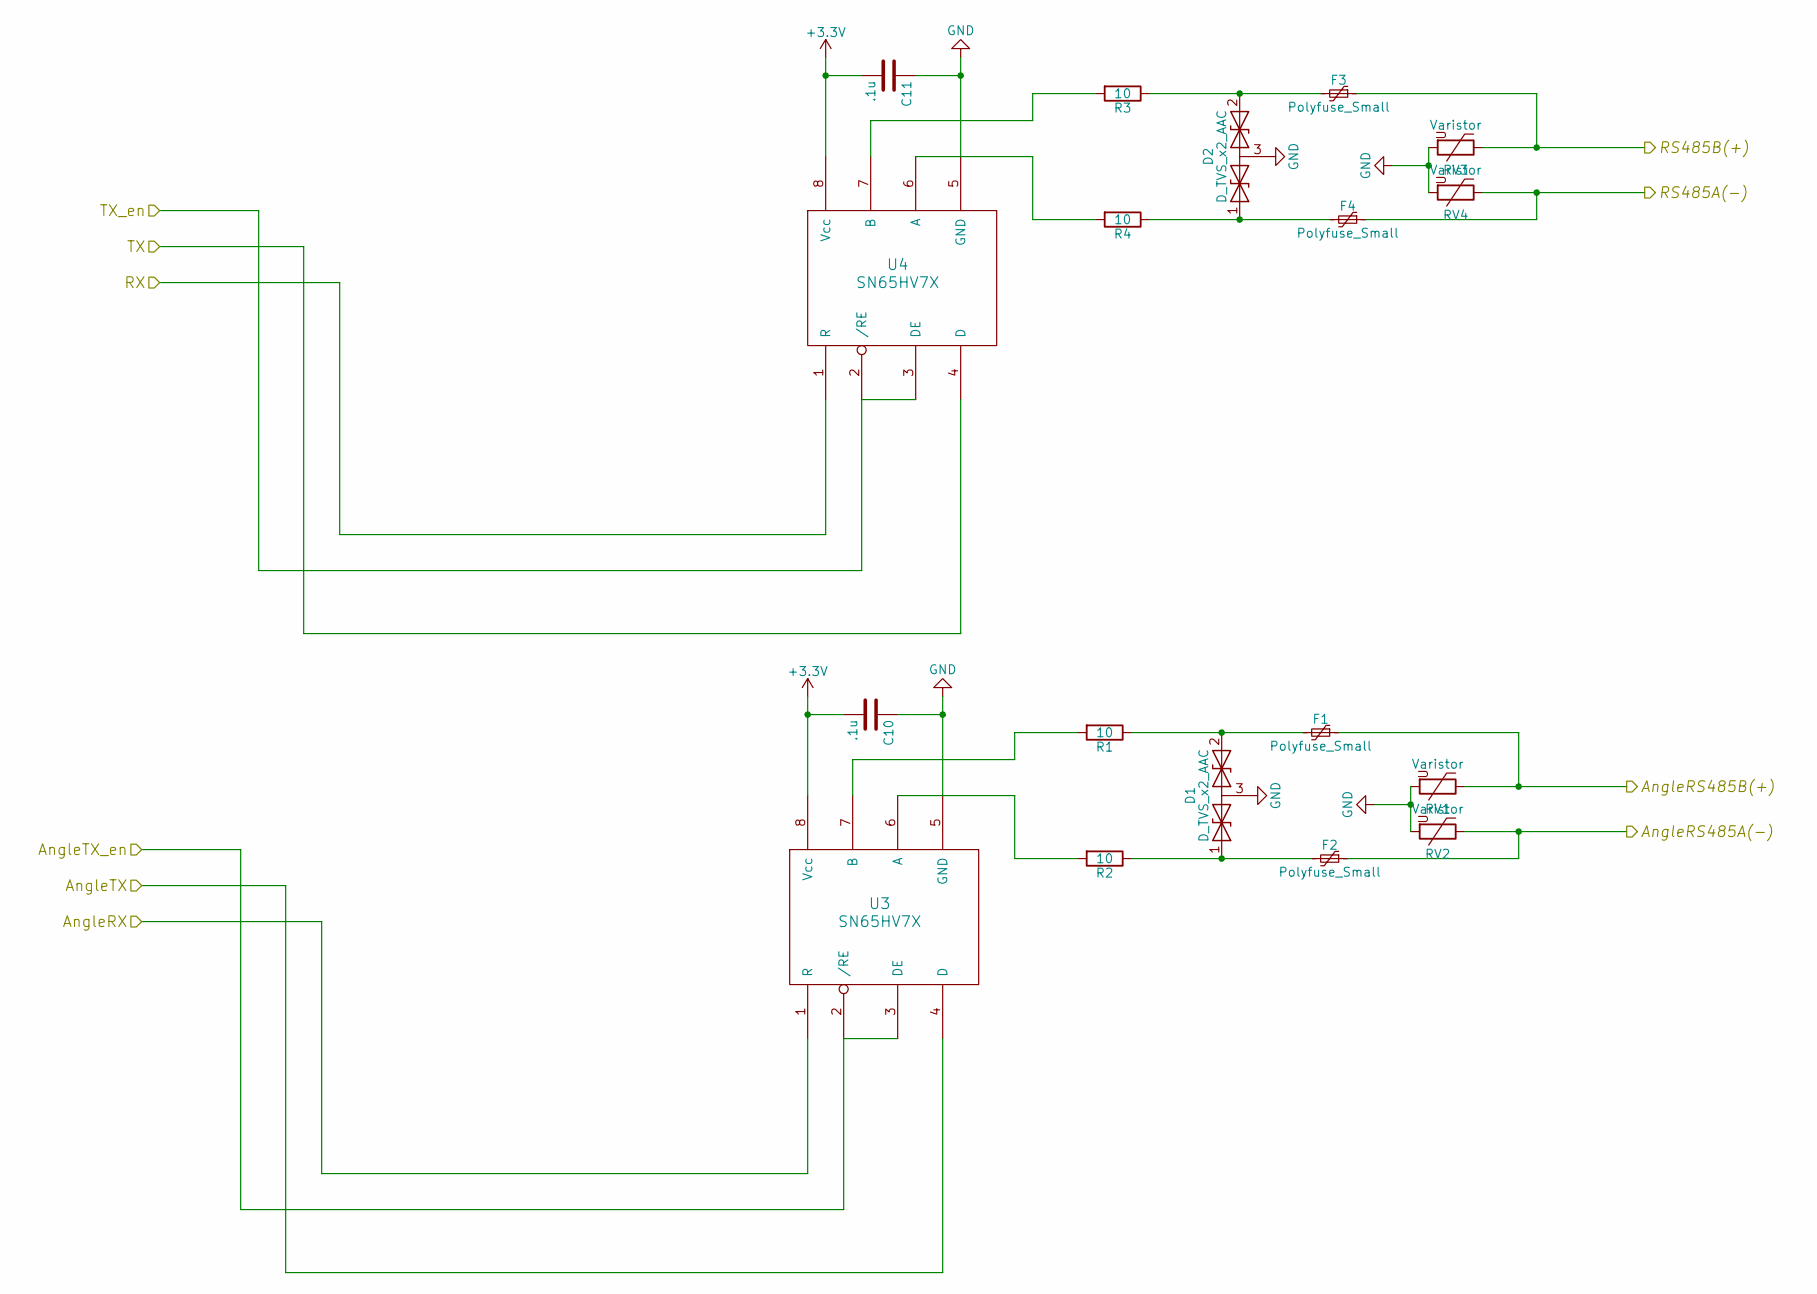
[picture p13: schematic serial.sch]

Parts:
C10, C11: .1u; C_1206_3216Metric
D1, D2: D_TVS_x2_AAC; SOT-23
F1, F2, F3, F4: Polyfuse_Small; R_1812_4532Metric
R1, R2, R3, R4: 10; R_2816_7142Metric_Pad3.20x4.45mm_HandSolder
RV1, RV2, RV3, RV4: Varistor; R_1210_3225Metric
U3, U4: SN65HV7X; SOIC-8_3.9x4.9mm_P1.27mm

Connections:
+3V3: C10.2, C11.2, U3.8 (Vcc), U4.8 (Vcc); also elsewhere on the board
/C-D/RS485A(-): F3.1, RV3.1; also elsewhere on the board
/C-D/RS485B(+): F4.1, RV4.1; also elsewhere on the board
/C-D/serial/AngleRS485A(-): F2.1, RV2.1; also elsewhere on the board
/C-D/serial/AngleRS485B(+): F1.1, RV1.1; also elsewhere on the board
/C-D/serial/AngleRX: U3.1 (R); also elsewhere on the board
/C-D/serial/AngleTX: U3.4 (D); also elsewhere on the board
/C-D/serial/AngleTX_en: U3.2 (/RE), U3.3 (DE); also elsewhere on the board
/C-D/serial/RX: U4.1 (R); also elsewhere on the board
/C-D/serial/TX: U4.4 (D); also elsewhere on the board
/C-D/serial/TX_en: U4.2 (/RE), U4.3 (DE); also elsewhere on the board
GND: C10.1, C11.1, D1.3 (common), D2.3 (common), RV1.2, RV2.2, RV3.2, RV4.2, U3.5 (GND), U4.5 (GND); also elsewhere on the board
unnamed: D1.1 (A1), F2.2, R2.1
unnamed: D1.2 (A2), F1.2, R1.1
unnamed: D2.1 (A1), F4.2, R4.1
unnamed: D2.2 (A2), F3.2, R3.1
unnamed: R1.2, U3.7 (B)
unnamed: R2.2, U3.6 (A)
unnamed: R3.2, U4.7 (B)
unnamed: R4.2, U4.6 (A)

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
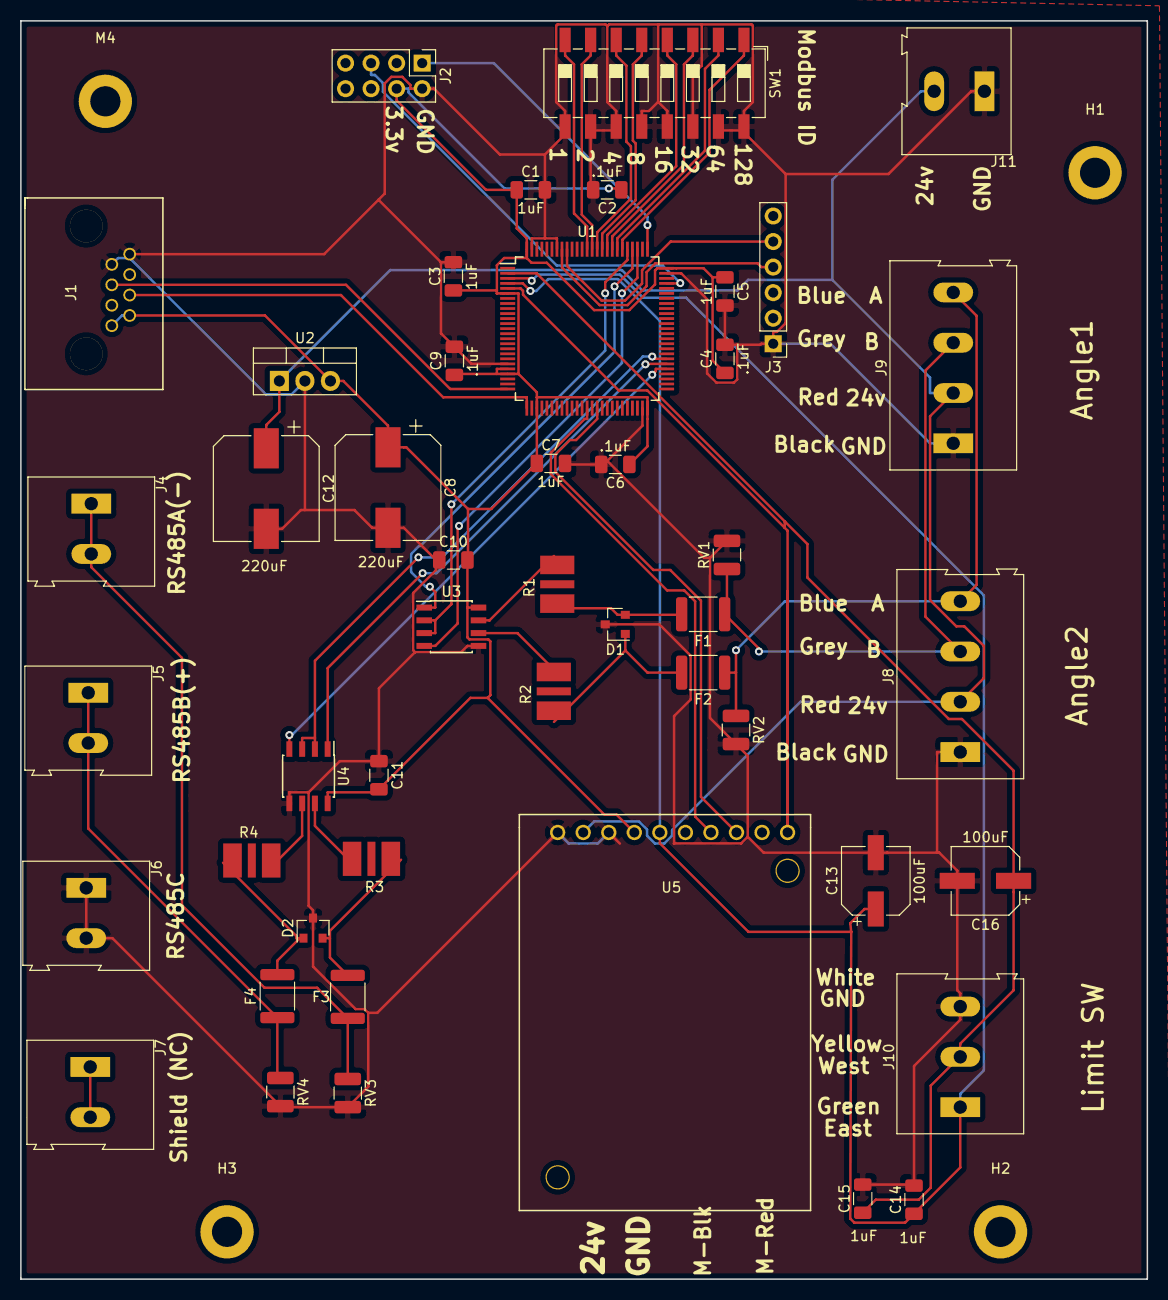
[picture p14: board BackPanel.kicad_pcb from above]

Board: 2 copper layers, 112.0 x 125.1 mm, 51 parts (0 on the bottom side), 40 nets.

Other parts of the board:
H1, H2, H3: MountingHole_5.3mm_M5
M4: MountingHole_5.3mm_M5

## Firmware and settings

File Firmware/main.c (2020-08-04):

/*
    ChibiOS - Copyright (C) 2006..2015 Giovanni Di Sirio

   Licensed under the Apache License, Version 2.0 (the "License");
    you may not use this file except in compliance with the License.
    You may obtain a copy of the License at

        http://www.apache.org/licenses/LICENSE-2.0

    Unless required by applicable law or agreed to in writing, software
    distributed under the License is distributed on an "AS IS" BASIS,
    WITHOUT WARRANTIES OR CONDITIONS OF ANY KIND, either express or implied.
    See the License for the specific language governing permissions and
    limitations under the License.
*/

#define CHPRINTF_USE_FLOAT   TRUE
#include "ch.h"
#include "hal.h"
#include "stdio.h"
#include "string.h"
#include "stdlib.h"
#include "math.h"
//#include "chprintf.h"
#include "hal_queues.h"
#include <string.h>
#include "stm32f3xx.h"

#define NO_ERROR 0
#define BAD_REGISTER 2
#define BAD_VALUE 3

#define STRAIN_ERROR 1
#define FAST_BLOW_ERROR 2
#define EAST_LIMIT_ERROR 3 
#define WEST_LIMIT_ERROR 4
#define STALL_ERROR 5
#define ANGLE_DIFF_ERROR 6
#define EAST_ANGLE_EXCEED_ERROR 7
#define WEST_ANGLE_EXCEED_ERROR 8
#define EMERGENCY_STOP_ERROR 9
// Create our initial arrays - I don't want this stuff on the stack

static uint16_t *flash1 = 0x803F000;

#define ADC_GRP1_NUM_CHANNELS   2

#define ADC_GRP1_BUF_DEPTH      1
size_t nx = 0, ny = 0;

static adcsample_t samples1[ADC_GRP1_NUM_CHANNELS * ADC_GRP1_BUF_DEPTH];
static uint8_t txbuf[10];
static uint8_t rxbuf[10];
static uint8_t step;
static uint8_t angleStarted =0;
static uint8_t angleCount =0;
static uint8_t x;
static uint8_t mode = 0; // 0 = auto 1 = manual
static float currentAngle1;
static float currentAngle2;
static float currentAngle;
static bool angleFlipFlop = false;
static float maxAmps = 0.0;
static float currentAmps;
static float lastAngle;
static float setPoint;
static uint8_t reset =0;
static mailbox_t RxMbx;
#define MAILBOX_SIZE 25
static msg_t RxMbxBuff[MAILBOX_SIZE];

static mailbox_t RxMbx2;
static msg_t RxMbx2Buff[MAILBOX_SIZE];

static mailbox_t SSMbx;
static msg_t SSMbxBuff[MAILBOX_SIZE];

static uint16_t stallSeconds =0;
static uint16_t strainSeconds =0;
static int16_t deg,speed,setpoint =0;
static float currentSpeed = 0.0;
static uint16_t parameters[10];
static float speedThresh = .1;  // threshold to tell if it is moving or not
static uint16_t fastAmpsThresh = 80;  // threshold to tell if it is moving or not
static uint16_t slowAmpsThresh = 50;  // threshold to tell if it is moving or not
static uint16_t error;
static uint16_t hysterisisDeg = 20; // these are in integers so that we can
                                    // maybe set them via modbus later

static float travelQueue[20];
static uint16_t stopDeg = 445;
static uint16_t stoptime = 66;
static uint16_t angleMode = 0;
static uint16_t angleDiff = 50;
static uint16_t running;
static uint8_t startMove;
static uint8_t eastLimit;
static uint8_t westLimit;

static uint8_t goingEast;
static uint8_t goingWest;

static double deg2;
static char rx_text[32][32];
static char rx2_text[32][32];
static char btn_state[32];
static int rx_queue_pos=0;
static int rx_queue_num=0;
static int rx2_queue_pos=0;
static int rx2_queue_num=0;
static int rx3_queue_pos=0;


static uint8_t my_address = 0x10;
static uint8_t inverted_address = 0;



static void adcerrorcallback(ADCDriver *adcp, adcerror_t err) {

  (void)adcp;
  (void)err;
  dbg('error!!');
}

static PWMConfig pwmcfg = {
  20000,                                    /* 10kHz PWM clock frequency.   */
  10,                                    /* Initial PWM period 1S.       */
  NULL,
  {
   {PWM_OUTPUT_ACTIVE_HIGH, NULL},
   {PWM_OUTPUT_DISABLED, NULL},
   {PWM_OUTPUT_DISABLED, NULL},
   {PWM_OUTPUT_DISABLED, NULL}
  },
  0,
  0
};



static const ADCConversionGroup adcgrpcfg1 = {
  FALSE,
  ADC_GRP1_NUM_CHANNELS,
  NULL,
  adcerrorcallback,
  ADC_CFGR_CONT,            /* CFGR    */
  ADC_TR(0, 4095),          /* TR1     */
  {                         /* SMPR[2] sample Register */
    0,
    ADC_SMPR2_SMP_AN18(ADC_SMPR_SMP_601P5)|ADC_SMPR2_SMP_AN13(ADC_SMPR_SMP_601P5)
  },
  {                         /* SQR[4]  Sequence Register - order & channel to read*/
      ADC_SQR1_SQ1_N(ADC_CHANNEL_IN13)|ADC_SQR1_SQ2_N(ADC_CHANNEL_IN18),
    0,
    0,
    0
  }
};




#define CS 0
#define CS2 1

#define CK 5
#define MISO 6
#define MOSI 7

#define a_lsb 0.061
#define g_lsb 0.00875


// this should set a timeout of .625 seconds (LSI = 40k / (64 * 1000))

static const WDGConfig wdgcfg = {
  STM32_IWDG_PR_64,
  STM32_IWDG_RL(1000),
  STM32_IWDG_WIN_DISABLED};

// This got redefined in a later version of Chibios for this board
#define GPIOA_PIN0 0
static const SPIConfig std_spicfg1 = {
  NULL,
  NULL,
  GPIOA,                                                        /*port of CS  */
  GPIOA_PIN0,                                                /*pin of CS   */
  //  SPI_CR1_CPOL|SPI_CR1_CPHA|		\
  //#  SPI_CR1_SPE|SPI_CR1_MSTR,
  0,
  SPI_CR2_DS_2 | SPI_CR2_DS_1 | SPI_CR2_DS_0                    /*CR2 register*/
};



void feedWatchdog(){
    if (!reset)
	wdgReset(&WDGD1);
}


void unlock_flash()
{
    if (FLASH->CR & FLASH_CR_LOCK){
	FLASH->KEYR = 0x45670123;
	FLASH->KEYR = 0xCDEF89AB;
    }


}


void erase_flash(uint16_t *flash)
{
    int x;
    unlock_flash();                        // must unlock flash before
					   // any write operations

    FLASH->CR |= FLASH_CR_PER;             // set page erase
    
    FLASH->AR = flash;                     // set page to flash
    
    FLASH->CR |= FLASH_CR_STRT;          // start erasing
    
    while ((FLASH->SR & FLASH_SR_BSY) == FLASH_SR_BSY); // loop till done
							// watchdog should
							// reset if it gets
							// stuck

    SET_BIT (FLASH->SR, (FLASH_SR_EOP));   // tech note RM0316 says to clear
    CLEAR_BIT (FLASH->CR, (FLASH_CR_PER)); // found note online that you must
                                           // clear this prior to writing
    
}


void write_flash(uint16_t value,uint16_t* flash)
{
    int x;
    //erase_flash(flash);


      
    SET_BIT(FLASH->CR, (FLASH_CR_PG));     // we are already unlocked, trying
					   // to do it again will mess
					   // things up
    
    *flash = value;                        // actually write the value
    //memcpy(flash,value,2);

    
    while ((FLASH->SR & FLASH_SR_BSY) == FLASH_SR_BSY); // loop till done
							// watchdog should
							// reset if it gets
							// stuck
    CLEAR_BIT (FLASH->CR, (FLASH_CR_PG));  // probably don't need to to this
					   // again
    
    SET_BIT (FLASH->SR, (FLASH_SR_EOP));   // tech note RM0316 says to clear
}





uint8_t spi_read(device,location)
{

  spiStart(&SPID1,device);
  spiSelect(&SPID1);
  txbuf[0] = 0x80 | location;
  spiSend(&SPID1,1,&txbuf);
  spiReceive(&SPID1,1,&rxbuf);
  spiUnselect(&SPID1);
  spiStop(&SPID1);
  return(rxbuf[0]);
}
void spi_write(device,location,data)
{
  spiStart(&SPID1,device);
  spiSelect(&SPID1);
  txbuf[0] = 0x00 | location;
  txbuf[1] = data;
  spiSend(&SPID1,2,&txbuf);
  spiUnselect(&SPID1);
  spiStop(&SPID1);
}





//static uint8_t vbuf[64][128];
//static uint8_t vbuf2[64][128];

static SerialConfig uartCfg =
{
    115200,// bit rate
    0,
    0,
    0,
};


static SerialConfig uartCfg2 =
{
    9600,// bit rate
    0,
    0,
    0,
};



dbg(char *string)
{
    chprintf((BaseSequentialStream*)&SD1,string);
    chThdSleepMilliseconds(100);
}


/*
 * Application entry point.
 */


/* *******************
stolen from http://www.modbustools.com/modbus.html#crc
*/
uint16_t CRC16 (const char *nData, uint16_t wLength)
{
static const uint16_t wCRCTable[] = {
   0X0000, 0XC0C1, 0XC181, 0X0140, 0XC301, 0X03C0, 0X0280, 0XC241,
   0XC601, 0X06C0, 0X0780, 0XC741, 0X0500, 0XC5C1, 0XC481, 0X0440,
   0XCC01, 0X0CC0, 0X0D80, 0XCD41, 0X0F00, 0XCFC1, 0XCE81, 0X0E40,
   0X0A00, 0XCAC1, 0XCB81, 0X0B40, 0XC901, 0X09C0, 0X0880, 0XC841,
   0XD801, 0X18C0, 0X1980, 0XD941, 0X1B00, 0XDBC1, 0XDA81, 0X1A40,
   0X1E00, 0XDEC1, 0XDF81, 0X1F40, 0XDD01, 0X1DC0, 0X1C80, 0XDC41,
   0X1400, 0XD4C1, 0XD581, 0X1540, 0XD701, 0X17C0, 0X1680, 0XD641,
   0XD201, 0X12C0, 0X1380, 0XD341, 0X1100, 0XD1C1, 0XD081, 0X1040,
   0XF001, 0X30C0, 0X3180, 0XF141, 0X3300, 0XF3C1, 0XF281, 0X3240,
   0X3600, 0XF6C1, 0XF781, 0X3740, 0XF501, 0X35C0, 0X3480, 0XF441,
   0X3C00, 0XFCC1, 0XFD81, 0X3D40, 0XFF01, 0X3FC0, 0X3E80, 0XFE41,
   0XFA01, 0X3AC0, 0X3B80, 0XFB41, 0X3900, 0XF9C1, 0XF881, 0X3840,
   0X2800, 0XE8C1, 0XE981, 0X2940, 0XEB01, 0X2BC0, 0X2A80, 0XEA41,
   0XEE01, 0X2EC0, 0X2F80, 0XEF41, 0X2D00, 0XEDC1, 0XEC81, 0X2C40,
   0XE401, 0X24C0, 0X2580, 0XE541, 0X2700, 0XE7C1, 0XE681, 0X2640,
   0X2200, 0XE2C1, 0XE381, 0X2340, 0XE101, 0X21C0, 0X2080, 0XE041,
   0XA001, 0X60C0, 0X6180, 0XA141, 0X6300, 0XA3C1, 0XA281, 0X6240,
   0X6600, 0XA6C1, 0XA781, 0X6740, 0XA501, 0X65C0, 0X6480, 0XA441,
   0X6C00, 0XACC1, 0XAD81, 0X6D40, 0XAF01, 0X6FC0, 0X6E80, 0XAE41,
   0XAA01, 0X6AC0, 0X6B80, 0XAB41, 0X6900, 0XA9C1, 0XA881, 0X6840,
   0X7800, 0XB8C1, 0XB981, 0X7940, 0XBB01, 0X7BC0, 0X7A80, 0XBA41,
   0XBE01, 0X7EC0, 0X7F80, 0XBF41, 0X7D00, 0XBDC1, 0XBC81, 0X7C40,
   0XB401, 0X74C0, 0X7580, 0XB541, 0X7700, 0XB7C1, 0XB681, 0X7640,
   0X7200, 0XB2C1, 0XB381, 0X7340, 0XB101, 0X71C0, 0X7080, 0XB041,
   0X5000, 0X90C1, 0X9181, 0X5140, 0X9301, 0X53C0, 0X5280, 0X9241,
   0X9601, 0X56C0, 0X5780, 0X9741, 0X5500, 0X95C1, 0X9481, 0X5440,
   0X9C01, 0X5CC0, 0X5D80, 0X9D41, 0X5F00, 0X9FC1, 0X9E81, 0X5E40,
   0X5A00, 0X9AC1, 0X9B81, 0X5B40, 0X9901, 0X59C0, 0X5880, 0X9841,
   0X8801, 0X48C0, 0X4980, 0X8941, 0X4B00, 0X8BC1, 0X8A81, 0X4A40,
   0X4E00, 0X8EC1, 0X8F81, 0X4F40, 0X8D01, 0X4DC0, 0X4C80, 0X8C41,
   0X4400, 0X84C1, 0X8581, 0X4540, 0X8701, 0X47C0, 0X4680, 0X8641,
   0X8201, 0X42C0, 0X4380, 0X8341, 0X4100, 0X81C1, 0X8081, 0X4040 };

char nTemp;
uint16_t wCRCWord = 0xFFFF;

   while (wLength--)
   {
      nTemp = *nData++ ^ wCRCWord;
      wCRCWord >>= 8;
      wCRCWord  ^= wCRCTable[nTemp];
   }
   return wCRCWord;
} // End: CRC16


				





static THD_WORKING_AREA(waThread3, 512);
static THD_FUNCTION(Thread3, arg) {
  (void)arg;
  int pass = 0;
  msg_t b = 0;

  chRegSetThreadName("serial");
  while(TRUE)
      {
	  
	  b = sdGetTimeout(&SD3,TIME_MS2I(2));

	  
	  if ((b!= Q_TIMEOUT) && (rx_queue_pos < 31))
	      {
		  //chprintf((BaseSequentialStream*)&SD1,"got char: %x\r\n",b);
		  rx_text[rx_queue_num][rx_queue_pos++]=b;
	      }
	  if ((b == Q_TIMEOUT) && (rx_queue_pos > 0))
	      {

		  rx_text[rx_queue_num][rx_queue_pos] = 0;

		  chMBPostTimeout(&RxMbx,(rx_queue_num<<8)|rx_queue_pos,TIME_INFINITE); // let our mailbox know
		  rx_queue_pos = 0;
		  // we have a new entry
		  rx_queue_num = (++rx_queue_num)%32;
		  memset(rx_text[rx_queue_num],0,5);
	      }
	  
  
      }

  return MSG_OK;
}


static THD_WORKING_AREA(waThread5, 512);
static THD_FUNCTION(Thread5, arg) {
  (void)arg;
  int pass = 0;
  msg_t b = 0;
  

  chRegSetThreadName("serial2");
  while(TRUE)
      {
	  
	  b = sdGetTimeout(&SD4,TIME_MS2I(3));

	  
	  if ((b!= Q_TIMEOUT) && (rx2_queue_pos < 31))
	      {
		  //chprintf((BaseSequentialStream*)&SD1,"got char: %x\r\n",b);
		  rx2_text[rx2_queue_num][rx2_queue_pos++]=b;
	      }
	  if ((b == Q_TIMEOUT) && (rx2_queue_pos > 0))
	      {
		  rx2_text[rx2_queue_num][rx2_queue_pos] = 0;

		  chMBPostTimeout(&RxMbx2,(rx2_queue_num<<8)|rx2_queue_pos,TIME_INFINITE); // let our mailbox know
		  rx2_queue_pos = 0;
		  // we have a new entry
		  rx2_queue_num = (++rx2_queue_num)%32;
		  memset(rx2_text[rx2_queue_num],0,5);
	      }
	  
  
      }

  return MSG_OK;
}





uint8_t decode_pos(char pos)
{
  return pos - 32;
}

void startTracker(){
  int x;
  if (startMove ==0){
    stallSeconds = 0;
    strainSeconds = 0;
    startMove = 1;
    chprintf(&SD1,"ResetQueue,\r\n");	    
    for (x=0;x<20;x++)
      travelQueue[x]=currentAngle;
  }
}

void updateFlash(){
  int x;
  erase_flash(flash1);
  parameters[7] = error;
  for (x=0;x<10;x++)
    write_flash(parameters[x],flash1+x);
}
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
int main(void) {
  unsigned i;
  float VDD;
  uint8_t count;
  
  /*
   * System initializations.
   * - HAL initialization, this also initializes the configured device drivers
   *   and performs the board-specific initializations.
   * - Kernel initialization, the main() function becomes a thread and the
   *   RTOS is active.
   */
  halInit();
  chSysInit();
  
  pwmStart(&PWMD1, &pwmcfg);
  palSetPad(GPIOB, 5);
  wdgStart(&WDGD1, &wdgcfg);
  sdStart(&SD1, &uartCfg);
  sdStart(&SD2, &uartCfg);
  sdStart(&SD3, &uartCfg2);
  sdStart(&SD4, &uartCfg2);

  palSetPadMode(GPIOD, 0, PAL_MODE_INPUT_PULLUP);   // address
  palSetPadMode(GPIOD, 1, PAL_MODE_INPUT_PULLUP);   // address  
  palSetPadMode(GPIOD, 2, PAL_MODE_INPUT_PULLUP);   // address
  palSetPadMode(GPIOD, 3, PAL_MODE_INPUT_PULLUP);   // address  
  palSetPadMode(GPIOD, 4, PAL_MODE_INPUT_PULLUP);   // address
  palSetPadMode(GPIOD, 5, PAL_MODE_INPUT_PULLUP);   // address  
  palSetPadMode(GPIOD, 6, PAL_MODE_INPUT_PULLUP);   // address
  palSetPadMode(GPIOD, 7, PAL_MODE_INPUT_PULLUP);   // address  

  
  feedWatchdog();
  chprintf((BaseSequentialStream*)&SD1,"Hello World - I am # %d\r\n",palReadPort(GPIOD) & 0xFF);
  inverted_address = palReadPort(GPIOD) & 0xFF;



  my_address = 0;
  my_address |= ((inverted_address & 0x01) << 7);
  my_address |= ((inverted_address & 0x02) << 5);
  my_address |= ((inverted_address & 0x04) << 3);
  my_address |= ((inverted_address & 0x08) << 1);
  my_address |= ((inverted_address & 0x10) >> 1);
  my_address |= ((inverted_address & 0x20) >> 3);
  my_address |= ((inverted_address & 0x40) >> 5);
  my_address |= ((inverted_address & 0x80) >> 7);
  
  chMBObjectInit(&RxMbx,&RxMbxBuff,MAILBOX_SIZE);
  chMBObjectInit(&RxMbx2,&RxMbx2Buff,MAILBOX_SIZE);
  chMBObjectInit(&SSMbx,&SSMbxBuff,MAILBOX_SIZE);
  palSetPadMode(GPIOE, 7, PAL_MODE_INPUT_ANALOG); // current

  adcStart(&ADCD3, NULL);
  // The referenece voltage enable MUST come after the adcStart 
  adcSTM32EnableTSVREFE();

  palSetPadMode(GPIOE, 3, PAL_MODE_INPUT_PULLUP); // e/w limit sw
  palSetPadMode(GPIOE, 4, PAL_MODE_INPUT_PULLUP);

  palSetPadMode(GPIOE, 5, PAL_MODE_OUTPUT_PUSHPULL); // east west
  palSetPadMode(GPIOE, 6, PAL_MODE_OUTPUT_PUSHPULL);
  stopTracker();
  


  
  /*
   * SPI1 I/O pins setup.
   */
  palSetPadMode(GPIOB, 6, PAL_MODE_ALTERNATE(7));   // UART1 - Debug
  palSetPadMode(GPIOB, 7, PAL_MODE_ALTERNATE(7));

  palSetPadMode(GPIOA, 2, PAL_MODE_ALTERNATE(7));  // UART2 - front panel
  palSetPadMode(GPIOA, 3, PAL_MODE_ALTERNATE(7));

  palSetPadMode(GPIOE, 9, PAL_MODE_ALTERNATE(2));   // PWM   


  
  palSetPadMode(GPIOD, 9, PAL_MODE_ALTERNATE(7));   // UART3 Loop  
  palSetPadMode(GPIOD, 8, PAL_MODE_ALTERNATE(7));
  palSetPadMode(GPIOD, 10, PAL_MODE_OUTPUT_PUSHPULL);

  palSetPadMode(GPIOC, 10, PAL_MODE_ALTERNATE(5));   // UART4 - Angle  
  palSetPadMode(GPIOC, 11, PAL_MODE_ALTERNATE(5));
  palSetPadMode(GPIOC, 12, PAL_MODE_OUTPUT_PUSHPULL);

  

  //palSetPadMode(GPIOB, 5, PAL_MODE_OUTPUT_PUSHPULL);
  //palSetPadMode(GPIOB, 8, PAL_MODE_INPUT_PULLUP);
  //palSetPadMode(GPIOB, 9, PAL_MODE_OUTPUT_PUSHPULL);
  //palSetPadMode(GPIOB, 15, PAL_MODE_OUTPUT_PUSHPULL);
  //palSetPadMode(GPIOB, 14, PAL_MODE_OUTPUT_PUSHPULL);
  // palSetPadMode(GPIOA, 1, PAL_MODE_OUTPUT_PUSHPULL);

  
  //palSetPadMode(GPIOA, 5, PAL_MODE_ALTERNATE(5)|PAL_STM32_OSPEED_HIGHEST);
  // palSetPadMode(GPIOA, 6, PAL_MODE_ALTERNATE(5)|PAL_STM32_OSPEED_HIGHEST);
  //palSetPadMode(GPIOA, 7, PAL_MODE_ALTERNATE(5)|PAL_STM32_OSPEED_HIGHEST);
  //palClearPad(GPIOA,1);
  //palSetPad(GPIOB,9);




  
  

  if (*flash1 == 0xffff){
    parameters[0]= fastAmpsThresh;
    parameters[1]= slowAmpsThresh;
    parameters[2] = hysterisisDeg;
    parameters[3] = stopDeg;
    parameters[4] = stoptime;
    parameters[5] = angleMode;
    parameters[6] = angleDiff;
    parameters[6] = error;
    chprintf((BaseSequentialStream*)&SD1,"Resetting Flash -\r\n");
    erase_flash(flash1);
    for (x=0;x<10;x++)
      chprintf((BaseSequentialStream*)&SD1,"Writing Flash %d = %d -\r\n",x,parameters[x]);

    for (x=0;x<10;x++)
      write_flash(parameters[x],flash1+x);
    
  }
  else{
      // flash has been written - use those values
      // init saved values in case we only choose to reset
      // just id or just address later.
    chprintf((BaseSequentialStream*)&SD1,"Getting Flash -\r\n");
    memcpy(parameters,flash1,20);
    fastAmpsThresh = parameters[0];
    slowAmpsThresh = parameters[1];
    hysterisisDeg = parameters[2];
    stopDeg = parameters[3];
    stoptime = parameters[4];
    angleMode = parameters[5];
    angleDiff = parameters[6];
    error = parameters[7];
    for (x=0;x<10;x++)
      chprintf((BaseSequentialStream*)&SD1,"Getting Flash %d = %d -\r\n",x,parameters[x]);
    //erase_flash(flash1);
  }

  



  // chprintf((BaseSequentialStream*)&SD2,"Hello World 2\r\n");
  chprintf((BaseSequentialStream*)&SD1,"Hello World - I am # %d\r\n",my_address);
  //  palSetPadMode(GPIOA, 0, PAL_MODE_OUTPUT_PUSHPULL);
  //palSetPadMode(GPIOA, 1, PAL_MODE_OUTPUT_PUSHPULL);        

  //palSetPadMode(GPIOB, 8, PAL_MODE_OUTPUT_PUSHPULL); 

  palClearPad(GPIOD, 10);   // Clear tx/rx for UART3
  palClearPad(GPIOC, 12);   // Clear tx/rx for UART4

  //palSetPad(GPIOA,CS);
  //  palSetPad(GPIOA,CS2);






    


  //  chThdCreateStatic(waThread1, sizeof(waThread1), NORMALPRIO, Thread1, NULL);

  chprintf((BaseSequentialStream*)&SD1,"HelloA\r\n")  ;
  chThdCreateStatic(waThread3, sizeof(waThread3), NORMALPRIO, Thread3, NULL);
  chprintf((BaseSequentialStream*)&SD1,"HelloB\r\n")  ;
  chThdCreateStatic(waThread4, sizeof(waThread4), NORMALPRIO, Thread4, NULL);
  chprintf((BaseSequentialStream*)&SD1,"HelloC\r\n")  ;
  
  chThdCreateStatic(waThread5, sizeof(waThread5), NORMALPRIO, Thread5, NULL);
  chThdCreateStatic(waThread6, sizeof(waThread6), NORMALPRIO, Thread6, NULL);
  chThdCreateStatic(waThread7, sizeof(waThread7), NORMALPRIO, Thread7, NULL);
  chThdCreateStatic(waThread8, sizeof(waThread8), NORMALPRIO, Thread8, NULL);

  uint32_t x,y;



  


  chprintf((BaseSequentialStream*)&SD1,"HelloD\r\n")  ;


  chThdSleepMilliseconds(500);
  chprintf((BaseSequentialStream*)&SD1,"\r\n");
  //  chThdCreateStatic(waThread2, sizeof(waThread2), NORMALPRIO, Thread2, NULL);

  chprintf((BaseSequentialStream*)&SD1,"Point B\r\n");
  requestAngle();
  chThdSleepMilliseconds(500);
  requestAngle();
  chThdSleepMilliseconds(500);
  updateAngles();
  setPoint = lastAngle = currentAngle;
  
  while (TRUE)
      {
	feedWatchdog();
	updateAngles();

	  westLimit = !(palReadPad(GPIOE,3));
	  eastLimit = !(palReadPad(GPIOE,4));
	  
	  if (error){
	      stopTracker();
	      count ++;
	      if (count%2==0){
		chprintf(&SD2,"@%c%c1\r\d",encodePos(4),encodePos(0));
		chprintf(&SD2,"@%c%c0\r\d",encodePos(4),encodePos(1));
	      } else {
		chprintf(&SD2,"@%c%c0\r\d",encodePos(4),encodePos(0));
		chprintf(&SD2,"@%c%c1\r\d",encodePos(4),encodePos(1));	      
	      }
	  } else {
	    chprintf(&SD2,"@%c%c0\r\d",encodePos(4),encodePos(0));
	    chprintf(&SD2,"@%c%c0\r\d",encodePos(4),encodePos(1));
	  }
	  
	  if (goingEast && (currentAngle > setPoint)){
	      stopTracker();
	      //chprintf(&SD2,"@%c%cStop     \r\n",encodePos(1),encodePos(10));
	  }
	  if (goingWest && (currentAngle < setPoint)){
	      stopTracker();
	      //chprintf(&SD2,"@%c%cStop     \r\n",encodePos(1),encodePos(10));
	  }

	  if ((startMove)&&(currentAngle<setPoint)){
	      startMove = 0;
	      //chprintf(&SD2,"@%c%cEast     \r\n",encodePos(1),encodePos(10));
	      chprintf(&SD1,"Move East \r\n");
	      goEast();
	  }
	  if ((startMove)&&(currentAngle>setPoint)){
	      startMove = 0;
	      //chprintf(&SD2,"@%c%cWest     \r\n",encodePos(1),encodePos(10));
	      chprintf(&SD1,"Move West \r\n");

	      goWest();
	  }
	  if (goingWest && (currentAngle < -stopDeg/10.0)){
	      error = WEST_ANGLE_EXCEED_ERROR;
	      updateFlash();
	      //chprintf(&SD2,"@%c%cWExceed %d \r\n",encodePos(1),encodePos(10),error);
	      stopTracker();
	  }
	  if (goingEast && (currentAngle > stopDeg/10.0)){
	      error = EAST_ANGLE_EXCEED_ERROR;
	      updateFlash();
	      //chprintf(&SD2,"@%c%cEExceed %d \r\n",encodePos(1),encodePos(10),error);
	      stopTracker();
	  }

	  if (running && (currentSpeed < speedThresh)){
	      stallSeconds = stallSeconds+1;
	  }
	  if (running && (currentSpeed > speedThresh)){
	      stallSeconds = 0;
	  }
	  if (running && (stallSeconds > stoptime)){
	      error = STALL_ERROR;
	      updateFlash();
	      stopTracker();
	      //chprintf(&SD2,"@%c%cStallErr %d \r\n",encodePos(1),encodePos(10),error);
	  }
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

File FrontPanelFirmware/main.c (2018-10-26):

/*

    ChibiOS - Copyright (C) 2006..2015 Giovanni Di Sirio

    Licensed under the Apache License, Version 2.0 (the "License");
    you may not use this file except in compliance with the License.
    You may obtain a copy of the License at

        http://www.apache.org/licenses/LICENSE-2.0

    Unless required by applicable law or agreed to in writing, software
    distributed under the License is distributed on an "AS IS" BASIS,
    WITHOUT WARRANTIES OR CONDITIONS OF ANY KIND, either express or implied.
    See the License for the specific language governing permissions and
    limitations under the License.
*/


#include "ch.h"
#include "hal.h"
#include "stdio.h"
#include "string.h"
//#include "stdlib.h"

#include <string.h>
#include "stm32f3xx.h"
//#include "star.h"
#include "font.h"

#define CS 9
#define RST 12
#define SPISELECT 11
#define CK 13
#define MISO 14
#define MOSI 15
#define DC 10



static uint8_t vbuf2[64][128];
volatile static uint8_t vbuf[64][128];
static uint8_t txbuf[2];
#define SOMC '@'
static uint8_t oled_current_row;
static uint8_t oled_current_column;


static mailbox_t KeyMbx,RxMbx,BeepMbx;
static binary_semaphore_t Keypressed;
#define MAILBOX_SIZE 25
//static msg_t KeyMbxBuff[MAILBOX_SIZE];
static msg_t RxMbxBuff[MAILBOX_SIZE];
//static msg_t BeepMbxBuff[MAILBOX_SIZE];
static char current_key =255;
static uint8_t current_row= 4;
static uint8_t strobe_wait= 1;

#define SLEEPSECONDS 3600

static int16_t sleep=0,sleepseconds=SLEEPSECONDS;
static char rx_text[32][32];
static int rx_queue_pos=0;
static int rx_queue_num=0;

static SerialConfig uartCfg =
{
    115200,// bit rate
    0,
    0,
    0,
};


static SerialConfig uartCfg2 =
{
    115200,// bit rate
    0,
    0,
    0,
};







static const SPIConfig std_spicfg0 = {
  NULL,
  NULL,
  GPIOB,                                                        /*port of CS  */
  9,                                                /*pin of CS   */

  //SPI_CR1_BR_2  |SPI_CR1_BR_1  |SPI_CR1_BR_0  |	\
  //SPI_CR1_SPE|SPI_CR1_MSTR,
  0,
  SPI_CR2_DS_2 | SPI_CR2_DS_1 | SPI_CR2_DS_0                    /*CR2 register*/
};






void spi_write0(location)
{
  spiStart(&SPID2,&std_spicfg0);
  spiSelect(&SPID2);
  txbuf[0] = location;
  spiSend(&SPID2,1,&txbuf);
  spiUnselect(&SPID2);
  spiStop(&SPID2);
}

void write_oled_command(char data)
{
    palClearPad(GPIOB,DC);
    spi_write0(data);
}


void write_oled_data(char data)
{
    palSetPad(GPIOB,DC);
    spi_write0(data);
}


void spi_write(location,data)
{
  spiStart(&SPID2,&std_spicfg0);
  spiSelect(&SPID2);
  txbuf[0] = location;
  txbuf[1] = data;
  spiSend(&SPID2,2,&txbuf);
  spiUnselect(&SPID2);
  spiStop(&SPID2);
}


void set_oled_text_pos(uint8_t x,uint8_t y)
{
    oled_current_column = (x*6+2);
    oled_current_row = (y*16);
}



void write_oled_char(char a)
{
    uint8_t j,i;

    for (j=0; j<16; j++)
	{
	    
	    for (i=0; i<6; i++)
		{
		    vbuf2[oled_current_row+j][oled_current_column+i] = font[a][j][i];
		}
	}
}


void oled_draw_string(uint8_t x,uint8_t y,char* text)
{
    //uint8_t currentx = x;
  uint8_t j;

  for (j=0;j<(strlen(text)-1);j++)
    {
      set_oled_text_pos(x+j,y);
      write_oled_char(text[j]);
    }
}



void init_spi()
{
  palSetPadMode(GPIOB, CS, PAL_MODE_OUTPUT_PUSHPULL);
  palSetPadMode(GPIOB, RST, PAL_MODE_OUTPUT_PUSHPULL);
  palSetPadMode(GPIOB, DC, PAL_MODE_OUTPUT_PUSHPULL);
  palSetPadMode(GPIOB, SPISELECT, PAL_MODE_OUTPUT_PUSHPULL);
  

  palSetPadMode(GPIOC, 0, PAL_MODE_INPUT_PULLUP);
  palSetPadMode(GPIOC, 1, PAL_MODE_INPUT_PULLUP);
  palSetPadMode(GPIOC, 2, PAL_MODE_INPUT_PULLUP);
  palSetPadMode(GPIOC, 3, PAL_MODE_INPUT_PULLUP);
  palSetPadMode(GPIOC, 4, PAL_MODE_INPUT_PULLUP);
  palSetPadMode(GPIOC, 5, PAL_MODE_INPUT_PULLUP);
  palSetPadMode(GPIOC, 6, PAL_MODE_INPUT_PULLUP);
  palSetPadMode(GPIOC, 7, PAL_MODE_INPUT_PULLUP);
  palSetPadMode(GPIOC, 8, PAL_MODE_INPUT_PULLUP);
  palSetPadMode(GPIOC, 9, PAL_MODE_INPUT_PULLUP);
//  palSetPadMode(GPIOD, 10, PAL_MODE_INPUT_PULLUP);
//  palSetPadMode(GPIOD, 11, PAL_MODE_INPUT_PULLUP);
//  palSetPadMode(GPIOD, 12, PAL_MODE_INPUT_PULLUP);
//  palSetPadMode(GPIOD, 13, PAL_MODE_INPUT_PULLUP);
//  palSetPadMode(GPIOD, 14, PAL_MODE_INPUT_PULLUP);
//  palSetPadMode(GPIOD, 15, PAL_MODE_INPUT_PULLUP);
//


  
  palSetPad(GPIOB,CS);
  palSetPad(GPIOB,RST);
  //palClearPad(GPIOB,CK);
  palClearPad(GPIOB,SPISELECT); // this actually selects SPI rather than 8 bit interface

}

void clear_oled()
{

    //chprintf(&SD1,"Did Clear OLED\r\n");
    memset(vbuf2,0x00,128*64); // I set the clear to be 0x11 instead of 0x00
    
                               // because the LCD would 'freak out' if lots
                               // of null data was sent

}



void shade_oled(uint8_t shade)
{
    memset(vbuf2,shade,128*10);
}




void init_oled()
{
      uint8_t i, j,x;


      chprintf(&SD1,"do oled command A\r\n");


  write_oled_command(0xfd); // Unlock 
  write_oled_data(0x12);

  write_oled_command(0xae | 0); // Set_Display_Off

  write_oled_command(0x15); // Set_Column_Address
  write_oled_data(0x1c);
  write_oled_data(0x5b);

  write_oled_command(0x75); // Set_Row_Address
  write_oled_data(0x00);
  write_oled_data(0x3f);

  write_oled_command(0xca); // Set_Multiplex_Ratio
  write_oled_data(0x3f);

  write_oled_command(0xa0); // Set_Remap_Format
  write_oled_data(0x14); 
  write_oled_data(0x11); 


  write_oled_command(0xb3); // Set_Display_Clock
  write_oled_data(0x31);  // was 22 (31)

  write_oled_command(0xc1); // Set_Contrast_Current
  write_oled_data(0xff);

  write_oled_command(0xc7); // Set_Master_Current
  write_oled_data(0x0f);

  write_oled_command(0xb9); // Set_Linear_Gray_Scale_Table();
  //write_oled_command(0x00); // enable gray scale table

  write_oled_command(0xb1); // Set_Phase_Length(0xE2); 
  write_oled_data(0xe2);

  write_oled_command(0xbb); // Set_Precharge_Voltage(0x1F);
  write_oled_data(0x1f);

  write_oled_command(0xb6); // Set_Precharge_Period(0x08);
  write_oled_data(0x08);

  write_oled_command(0xbe); // Set_VCOMH(0x07);
  write_oled_data(0x00);



    write_oled_command(0xA5); // set display all on

  
    //clear_oled(); 
  write_oled_command(0xae | 1); // Set_Display_On_Off(0x01);
  write_oled_command(0xa4 | 0x02); // Set_Display_Mode(0x02);
  write_oled_command(0x5c);
  palSetPad(GPIOB,DC);
  
}


void graphics_init()
{
  uint8_t row;
  uint8_t col;


  clear_oled();
  oled_draw_string(1,0,"Tracker Replacement ");
  //clear_oled();
  oled_draw_string(5,2,"SecureFutures ");
  //oled_draw_string(4,3,"& 4W Alignment ");


}




dbg(char *string)
{
    chprintf((BaseSequentialStream*)&SD1,string);
}


/*
 * Application entry point.
 */



uint32_t checksum()
{
    uint32_t checksum;
    int i;
    int j;
    checksum =0;
    for (i=0;i<64;i++)
	for(j=0;j<128;j++)
	    checksum = checksum+vbuf2[i][j];
    return checksum;
}
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

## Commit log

2018-07-03 Added modbus comms for the angle sensor and added ADC for the amps out on the motor
2018-07-04 Added a modbus method to change the setpoint and limit switches in the main code
2018-09-10 added outline for front panel
    [FrontPanel.dxf]
2018-09-10 added new kicad project and supporting submodules
    [FrontPanel.kicad_pcb, FrontPanel.sch]
2018-09-10 add front panel schematic
    [pwr.sch, rs485.sch, sw-led.sch]
2018-09-17 added old updates prior to installing kicad 5
2018-09-17 save prior to updating to kicad 5
    [FrontPanel.dsn, FrontPanel.sch, pwr.sch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]
2018-09-21 added back panel circuitboard
    [BackPanel-2018-09-17-19-39-30.sch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]
2018-10-02 get ready to transfer back to main computer
    [FrontPanel-2018-09-21-07-44-51.sch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]
2018-10-02 add code to timeout after an hour and then hide display - wake up on push of any button
2018-10-04 add code for new board
2018-10-15 add pwm for the motor
2018-10-15 Add pwm
    [GPIOE.sch, _saved_FrontPanel.sch]
2018-10-17 update circuit board with new changes;
    [BackPanel-B.Cu.gbr, BackPanel-B.Mask.gbr, BackPanel-B.Paste.gbr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]
2018-11-08 invert switch by software because board was labeled wrong
    [main.c]
2018-12-03 Made a queue for the angles to better keep track of motion
2020-08-04 Add all files and check in prior to mothballing
    [BackPanel.csv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]
